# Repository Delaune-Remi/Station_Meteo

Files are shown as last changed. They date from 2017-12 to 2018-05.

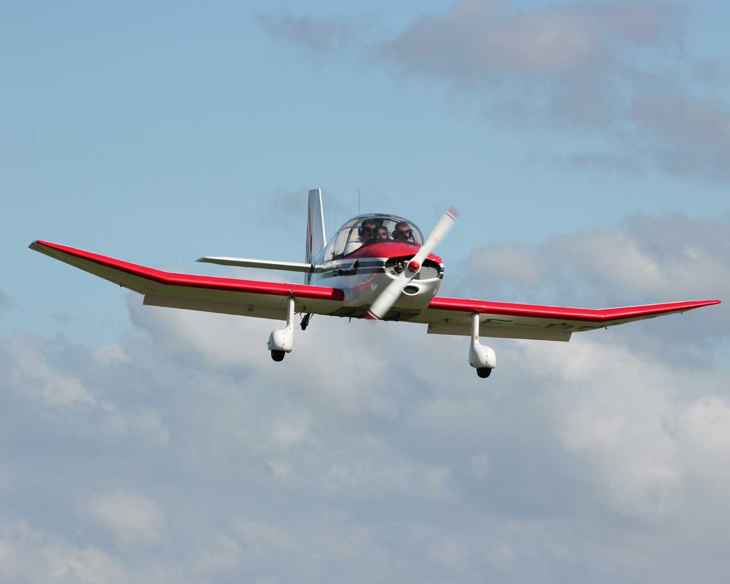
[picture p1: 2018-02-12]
Partie_Alexandre/Test_Unitaire/Prototype_HTML/images/fond.jpg

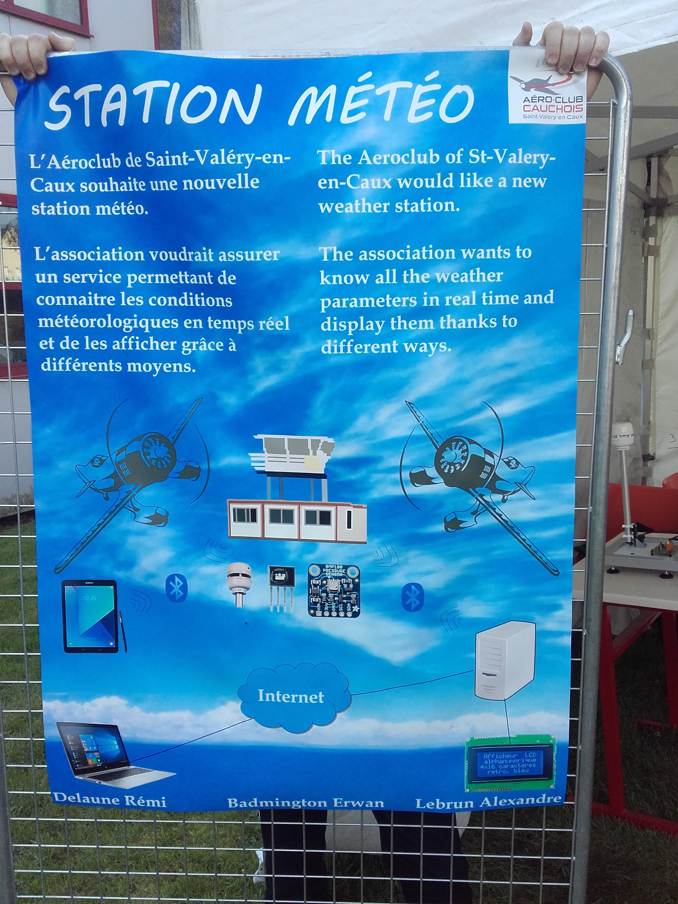
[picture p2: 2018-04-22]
Partie_Remi/Images/IMAGE PROJET/Poster.jpg

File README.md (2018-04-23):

<p  align="center">
  
  
</p>

---

<h1 align="center"> Station Meteo </h1>

---

<h2 align="center"> Presentation  </h2>

---

Station Meteo

<h4 align="center">Lien vers l'Aerodrome de Saint-Valery-En-Caux : http://aeroclub.cauchois.free.fr/</h4>

---

<h2 align="center"> Sommaire </h2>

---

* <a href="https://github.com/Delaune-Remi/Station_Meteo/tree/master/Analyse_Fonctionnelle" title="SysML">Analyse Fonctionnelle</a>
* <a href="https://github.com/Delaune-Remi/Station_Meteo/tree/master/Compte%20Rendu" title="Compte Rendu">Compte Rendu</a>
* <a href="https://github.com/Delaune-Remi/Station_Meteo/tree/master/Documentation" title="Documentation Technique">Documentation</a>
* <a href="https://github.com/Delaune-Remi/Station_Meteo/tree/master/Partie_Alexandre" title="Etudiant 2">Partie Alexandre</a>
* <a href="https://github.com/Delaune-Remi/Station_Meteo/tree/master/Partie_Erwan" title="Etudiant 3">Partie Erwan</a>
* <a href="https://github.com/Delaune-Remi/Station_Meteo/tree/master/Partie_Remi" title="Etudiant 1">Partie Remi</a>

---

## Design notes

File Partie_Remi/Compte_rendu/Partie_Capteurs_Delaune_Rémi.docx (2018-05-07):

Partie Capteurs

Projet Station Météo

Delaune Rémi

05/02/2018

Cette partie recense les différents capteurs et protocoles utilisé pour la station Météorologique

# Tables des Matières

# Introduction

Cette partie essentielle au bon fonctionnement de la station météorologique gère tous les capteurs qui seront placés en haut du mât de l’aéroclub cauchois représenté ci-dessous, les capteurs sont au nombre de 3, un capteur CV3F (girouette) utilisant le protocole NMEA, un capteur d’hygrométrie et un capteur de pression dont les fonctionnements seront expliqués.

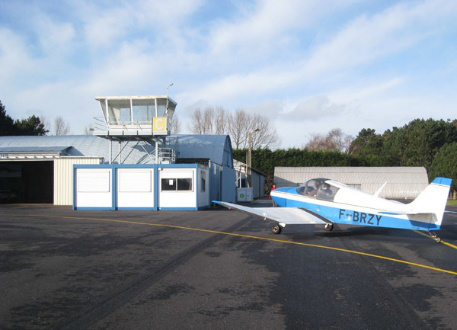
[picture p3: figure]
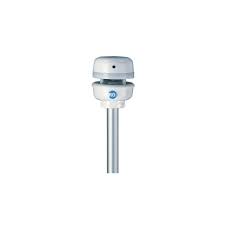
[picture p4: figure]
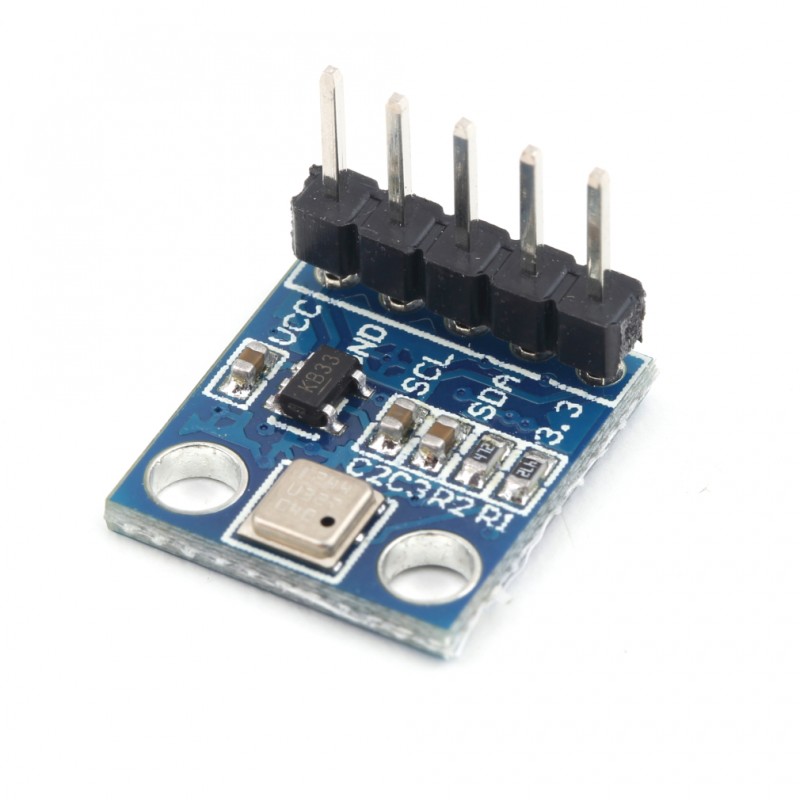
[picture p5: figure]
RÃ©sultat de recherche d'images pour "BMP180"
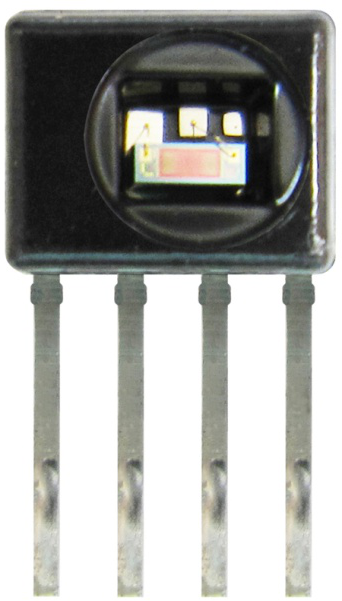
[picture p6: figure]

De plus, pour pouvoir communiquer entre les différentes parties du projet, j’ai proposé un protocole de transmission, le protocole INIMEAC.

Suite à de multiples tests avec l’application Android qui ont permis de déceler un problème de décodage de la trame par celle-ci, m’a amené à créer 2 protocoles INIMEAC en collaboration avec les autres parties dont le fonctionnement seront expliqués et détaillés.

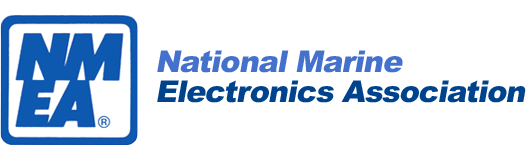
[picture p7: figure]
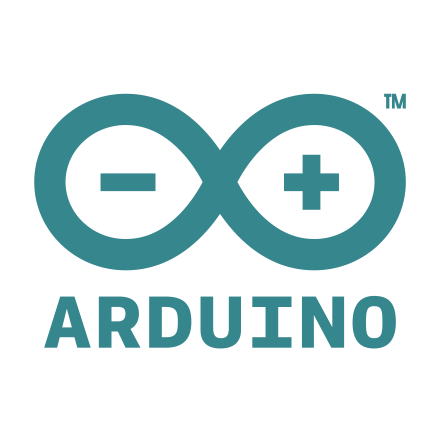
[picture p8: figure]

# Capteur CV3F

# Capteur CV3F

## Description:

Le capteur CV3F est une girouette ayant trois principales fonctions qui sont :

1. La mesure de la vitesse du vent
2. La direction du vent
3. La température de l'air

Afin de communiquer avec les différents systèmes, le capteur utilise les trames NMEA0183.

## Norme NMEA0183:

La norme NMEA0183 est spécialisé dans la communication entre équipements marins dont les équipements GPS (Global Positioning System). Celle-ci utilise une simple communication série pour transmettre une "phrase" à un ou plusieurs équipements, elle utilise le codage ASCII.

Exemple de trame NMEA0183:

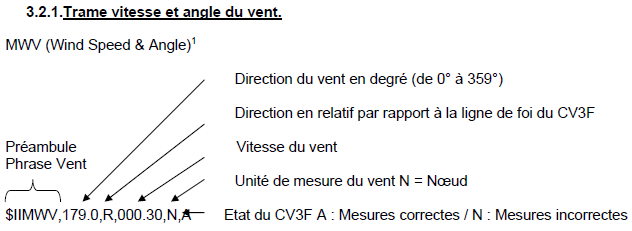
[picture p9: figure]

# Capteur CV3F

Afin d'établir une communication entre le capteur CV3F et la carte Arduino, il est nécessaire d'adapter les tensions car le capteur envoie une tension de sortie est du différentiel en 0-12V, tandis que la carte Arduino tolère une tension comprise entre 0 et 5V.

## Adaptation de tensions:

Pour faire cette adaptation de tensions, la méthode utilisé est le pont diviseur de tensions comme défini ci-dessous:

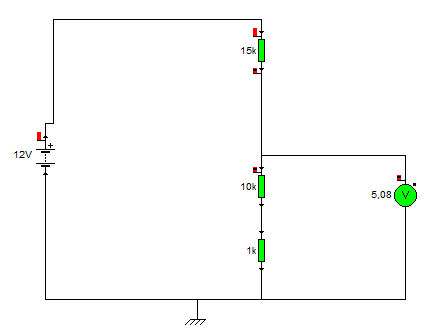
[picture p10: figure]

## Branchement du Capteur:

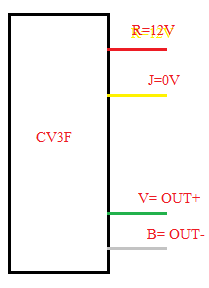
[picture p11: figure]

# Capteur CV3F

Le branchement du capteur CV3F est représenté ci-dessus, la sortie "OUT+" est relié au pont diviseur de tension pour sortir du 5V max en entrée de l'Arduino.

Les sorties "OUT+" et "OUT-" sont des sorties différentielles permettant la transmission des données du capteur (trame NMEA0183). La sortie "OUT-" n'est pas relié au système car elles sont en différentielle.

## Sécurité du Capteur:

Afin d'améliorer la sécurité du capteur et du système, j'ai ajouté une gaine thermique pour éviter tout risques d'arc-électrique.

## Programme pour récupérer les trames NMEA0183:

Pour récupérer les trames NMEA0183, j'ai réalisé le programme suivant:

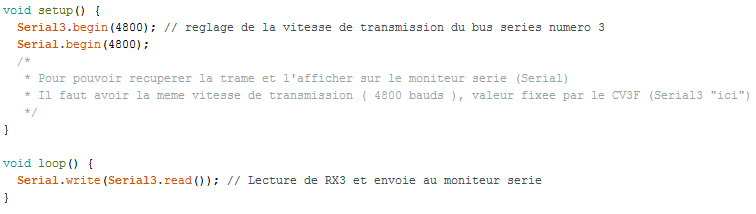
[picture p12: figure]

Lecture de la trame NMEA0183 reçue sur le moniteur Série:

# Capteur BMP180

# Capteur BMP180:

## Description:

Le capteur BMP180 est un capteur de pression ayant trois principales fonctions qui sont :

1. La pression
2. L'altitude
3. La température de l'air

Pour communiquer avec les différents systèmes, le capteur utilise le protocole I2C.

Afin de répondre au cahier des charges données, j'ai choisi de prendre le capteur de pression BMP180 pour acquérir la pression et la température de l'air, le capteur à une plage de pression allant de 950Hpa à 1050Hpa avec une précision de 0,12Hpa et une plage de température allant de -40°C à 85°C avec une résolution de 0,1°C.

De plus, il est indispensable de récupérer la température à l'aide du capteur BMP180 car la plage de température du capteur CV3F n'est pas suffisant et n'accepte pas les valeurs négatives.

Ce capteur correspond bien au cahier des charges qui a donné comme critères, une précision de pression de 1Hpa avec une précision de température de 0,5°C.

# Capteur BMP180

## Programme pour récupérer la température et la pression :

Le programme réalisé est le suivant:

La partie pour récupérer la température est ci-dessous:

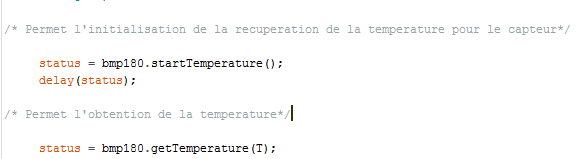
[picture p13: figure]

La partie permettant de récupérer la pression est ci-dessous:

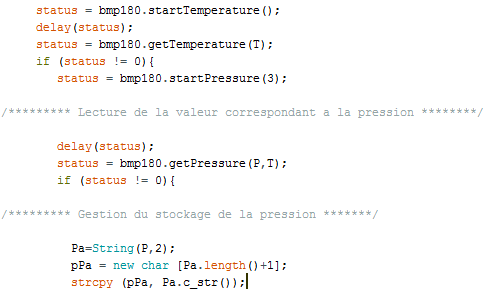
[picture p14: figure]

# Capteur BMP180

## Résultats des récupérations :

Récupération de la pression:

Récupération de la température

# Capteur HIH 8120

# Capteur HIH 8120 :

## Description :

Le capteur HIH 8120 est un capteur d'humidité permettant de mesurer 2 grandeurs physiques qui sont:

- La Température
- L'Hygrométrie

Afin de répondre au cahier des charges concernant la précision du capteur, j'ai opté pour le capteur HIH 8120 qui a une précision de 2 % pour l'hygrométrie et de 0,5 °C pour la température alors le cahier des charges nous oblige d'avoir une précision en température de 0,5°C ainsi qu'une précision de 2% pour l'humidité.

De plus le capteur HIH 6130 proposé au début du projet ne correspond pas à ces critères alors que le capteur choisi correspond parfaitement.

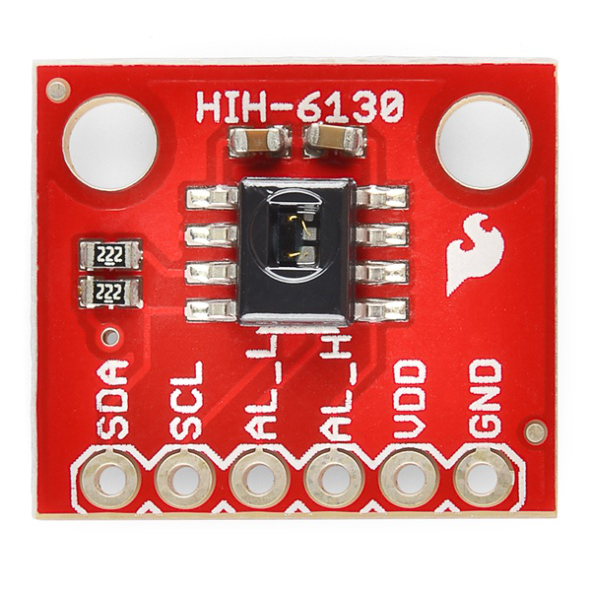
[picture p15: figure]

## Tests Unitaires pour récupération de l'hygrométrie :

# Capteur HIH 8120

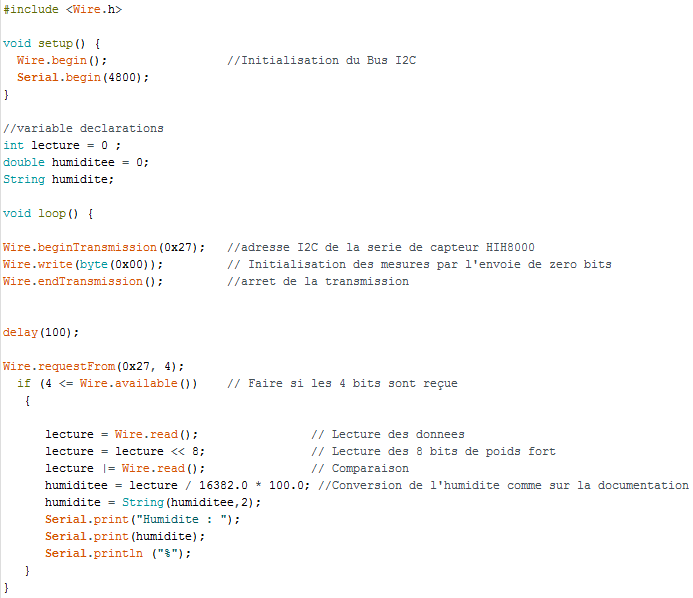
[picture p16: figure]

## Résultats des récupérations :

Le résultat est le suivant :

# Protocole INIMEAC

# Protocole INIMEAC :

Le protocole INIMEAC est un protocole qui permet de communiquer entre les différentes parties, entre autres il permet la transmission des données récupéré via les différents capteurs.

Suite à de multiples tests, ce protocole c’est scindé en 2 protocoles INIMEAC différents à cause des applications les utilisant, il y a le protocole initial pour communiquer entre les capteurs et la partie serveur web/afficheur, d’autres part un deuxième protocole qui est destiné à l’application Android, c’est 2 protocoles utilisent la norme Bluetooth v.2.0, de ce fait la distance maximale de transmission est limité à 20 mètres, la vitesse de transmission des données a été mis à 9600 Bauds.

## Protocole INIMEAC pour Serveur Web:

Ce protocole sert

© Projet Station Météo Page 12

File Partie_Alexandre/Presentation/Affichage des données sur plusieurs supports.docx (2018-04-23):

Affichage des données sur plusieurs supports

LEBRUN Alexandre

# Présentation

Cette partie du projet consiste à afficher les données reçu par la liaison série Bluetooth. Ces données seront afficher sur 2 afficheurs I2C puis sera visualisable sur un navigateur web. Suite au cahier des charges, nous avons eu besoin de deux afficheurs, de 2 lignes et de 16 caractères, au lieu d'un seul à cause du manque de place.

## Montage globale :

Voici le montage globale concernant ce projet ci-dessous :

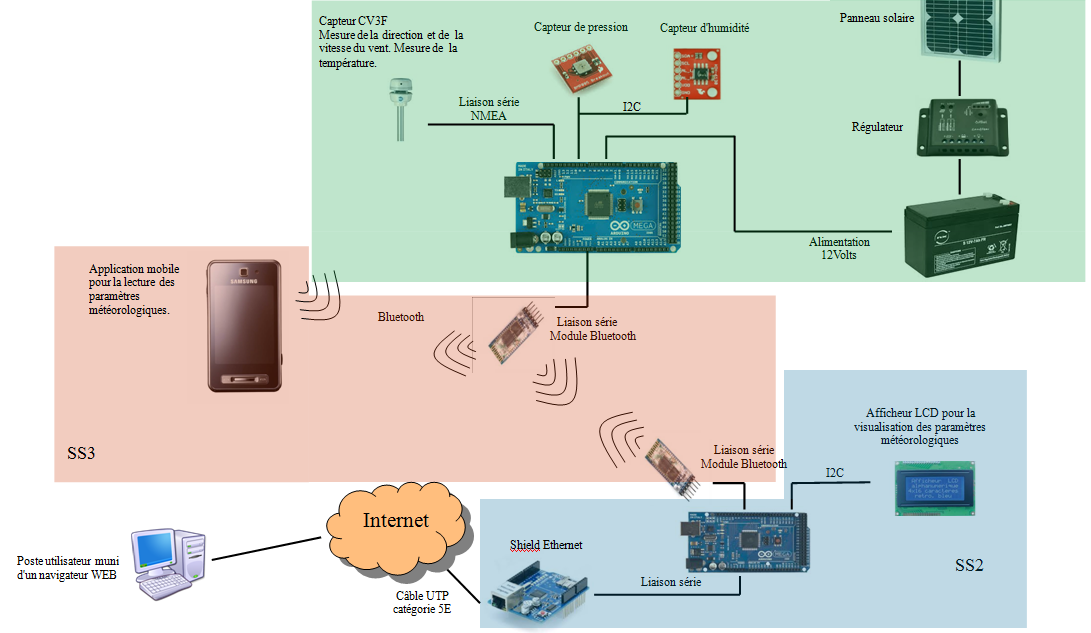
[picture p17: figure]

# Présentation du matériel

## Carte Arduino MEGA 2560 :

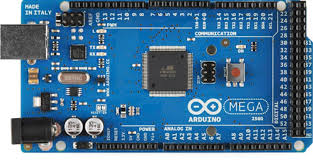
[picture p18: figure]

Cette carte permet de contrôler le flux Bluetooth la gestion des afficheurs, cette MEGA possède 256Ko d'espace mémoire.

## Shield Ethernet :

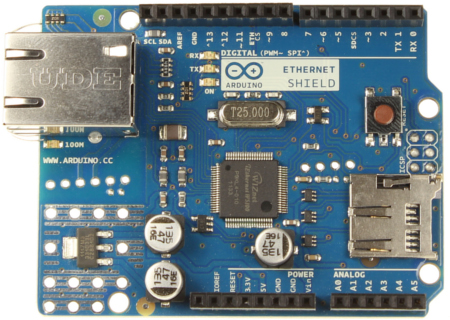
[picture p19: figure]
RÃ©sultat de recherche d'images pour "Shield ethernet"

Ce Shield permet de stocker un site web en mémoire grâce à une carte SD ou directement sur la mémoire de l'arduino, elle possède 16Ko d'espace mémoire et un emplacement SD ( Cette emplacement SD n'est pas utilisée ), Ce Shield Ethernet est relié avec la carte Arduino 4 broches SCLK MOSI MISO SS.

Le bus SPI : Ce bus est un protocole d'échanges de données qui travailles en full-duplex ( dans les deux sens ), ce bus permet la communication des données entre appareil par un protocole maître/esclave, le maître comme le nom l'indique gère tout. Ce bus envoie des informations sous forme binaire 0 ou 1 et utilise 4 signaux logiques :

- SCLK — Serial Clock, Horloge (généré par le maître)
- MOSI — Master Output, Slave Input (généré par le maître)
- MISO — Master Input, Slave Output (généré par l'esclave)
- SS — Slave Select, Actif à l'état bas (généré par le maître)

## Câble RJ45 :

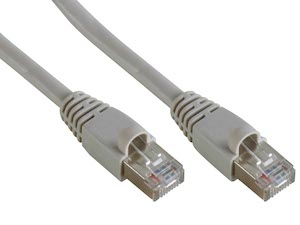
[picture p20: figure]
La prise RJ45 (http://www.lextronic.fr)

La prise RJ45 est une prise permettant d'interconnecter un appareil sur le réseau ici notre Shield Ethernet au réseau. Dans les spécifications le câble RJ45 doit être de pair torsadée non blindée ( UTP ) et de catégorie 5E.

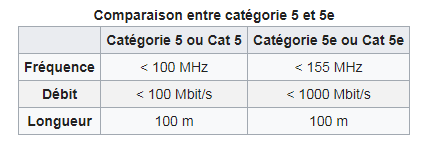
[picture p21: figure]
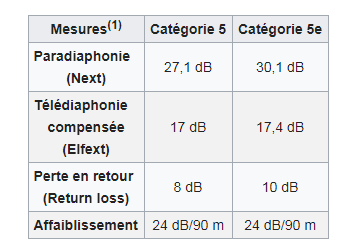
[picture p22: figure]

## Afficheur 2x16 I2C :

Cette afficheur fonctionne avec un module I2C CLCD420C, comme le nom l'indique l'afficheur fonctionne avec le bus I2C.

le bus I2C : Ce bus est un bus série asynchrone en half-duplex ( un sens à la fois ) il est multi-maître et multi-esclave, ce bus utilise deux signaux ( et une masse commune ) :

- SCL (Serial Clock) : l'horloge commune à tous les équipements,
- SDA (Serial Data) : la ligne portant les données.

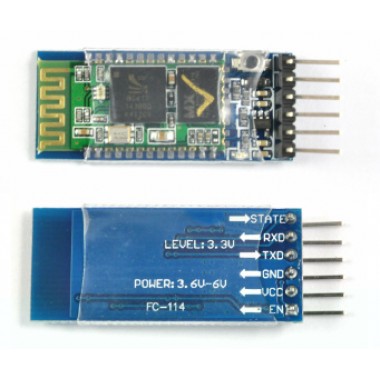
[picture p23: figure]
RÃ©sultat de recherche d'images pour "Module HC-05 bluetooth"

## Module HC-05 :

Ce module Bluetooth à été configuré par l'étudiant 3 Badmington Erwan, cet étudiant à configuré ce module en mode réception ce qui permet la réception du signal émit par les capteurs se trouvant sur la carte de l'étudiant 1 Delaune Rémi.

Nous avons décider de mettre les modules Bluetooth émission et réception sur les broches du port série 3 de la carte Arduino.

## Montage :

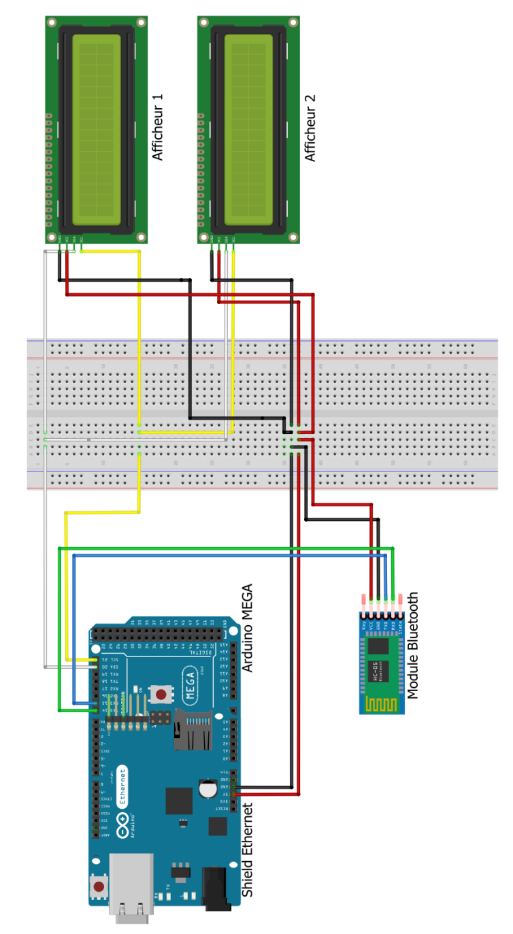
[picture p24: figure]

Explication du montage :

NOIR : On réalise une masse commune sur la platine

ROUGE : On réalise un 5V commun sur la platine

SCL : On réalise un SCL commun sur la platine

SDA : On réalise un SDA commun sur la platine

TX3 : Relié au RX du module Bluetooth

RX3 : Relié au TX du module Bluetooth

# Test Unitaire

Chaque test unitaire ont été réalisés sous l'environnement de travail ( IDE ) Arduino, Les ressources utilisées sont arduino.cc, openclassroom.com et github.com

## Test Reception Bluetooth :

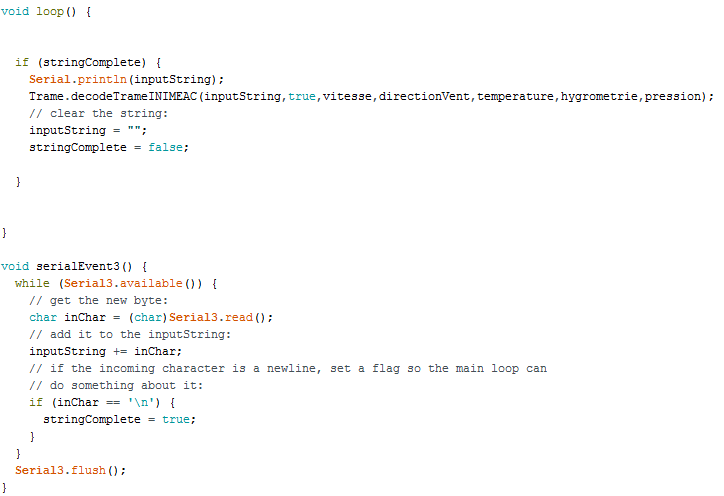
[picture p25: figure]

J'ai repris l'exemple du serialEvent se trouvant sur le site arduino.cc

On reçoit bien la trame que m'envoie Rémi

avec Ici : 0,1 kts en vitesse vent, 271° en direction vent, 22,55°C en temperature, 56,61% pour l'humidité et 1000,26 hPa en pression atmospherique.

## Test Afficheur :

Dans ce test unitaire j'ai testé l'affichage du mot bonjour sur l'afficheur lcd cette afficheur possède une bibliothèque CLCD.h trouvé sur internet.

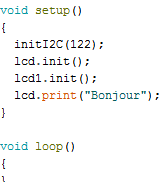
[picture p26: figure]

On affiche bien bonjour sur l'afficheur portant l'adresse 0x00 qui est réglable sur le module CLCD

## Test shield ethernet :

J'ai crée une adresse MAC pour le shield Ethernet qui est : 90-98-97-00-05-AB et j'ai fais une réservation sur le serveur DHCP du lycée pour mon adresse IP pour qu'il appartiennent sur le même réseau local j'ai décidé l'adresse suivante : 192.168.190.123.


## Dans ce test on affiche les informations côtés client : quel navigateur utilise t'il, quel paquet envoie t-il, à quel adresse il l'envoie, etc...

## Test page HTML :

Dans ce test unitaire je souhaite crée une page HTML qui serait capable de lire des broches de l'arduino je vous présente ce code ci-dessous :


Dans ce test on lit les valeurs lisibles sur les broches de A0 à A5 avec une petite interface sur le navigateur web le résultat est le suivant :


Avec ce test unitaire j'ai pu faire un prototype du site web final sous notepad++ :


J'ai pu réaliser par la suite un prototype d'interface pour l'afficheur I2C

Création d'une bibliothèque pour crée des caractères spéciaux pour afficheur I2C crée avec Arthur Langlois


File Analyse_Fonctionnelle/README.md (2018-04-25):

<h1 align="center"> Presentation </h1>

<table>
<tr align="center">
<td colspan="2">Vous trouverez dans le fichier Station_Meteo.eap les differents diagrammes presentes ci-dessous	 
ce fichier est ouvrable avec Entreprise Architect.
</td>
<tr align="center">
<td>Le fichier Scenario_Cas__Utilisation.odt contient les scenarios que la station meteo peut realiser. 
</td>
</tr>
</table>

---

#### _Exigence.png_
<p  align="center">
  
</p>

---

#### _UseCase.png_
<p  align="center">
  
</p>

---

#### _Sequence.png_ 
<p  align="center">
  
</p>

---

#### _DefinitionBlocs.png_
<p  align="center">
  
</p>

---

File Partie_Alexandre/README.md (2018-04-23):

---

<h1 align="center"> Sommaire </h1>
<p  align="center">
  
</p>

---

* <a href="https://github.com/Delaune-Remi/Station_Meteo/tree/master/Partie_Alexandre/Bibliotheque" title="Pour Arduino">Bibliotheque</a>
* <a href="https://github.com/Delaune-Remi/Station_Meteo/tree/master/Partie_Alexandre/Image" title="Image">Image</a>
* <a href="https://github.com/Delaune-Remi/Station_Meteo/tree/master/Partie_Alexandre/Presentation" title="Presentation">Presentation</a>
* <a href="https://github.com/Delaune-Remi/Station_Meteo/tree/master/Partie_Alexandre/Programme_Final" title="Programme Final">Programme Final</a>
* <a href="https://github.com/Delaune-Remi/Station_Meteo/tree/master/Partie_Alexandre/Test_Unitaire" title="Test Realiser">Test Unitaire</a>

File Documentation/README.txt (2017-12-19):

Cette partie servira a stocker les documentations utile pour le projet

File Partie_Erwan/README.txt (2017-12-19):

Cette partie permet a l'etudiant Erwan Badmington de gerer sa partie du Projet (Application Android)

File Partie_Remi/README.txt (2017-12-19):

Cette partie permet a l'etudiant Remi Delaune de gerer sa partie du Projet (Gestion des capteurs)

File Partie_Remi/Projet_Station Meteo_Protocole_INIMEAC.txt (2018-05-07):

Protocole INIMEAC :

&#!INIMEAC;!SWD::000.00::KTS;!DWD::000.00::D;!TMP::00.00::C;!RHY::000.00::%;!RPA::1013.25::hPa;!VAD::N:*

Légende:

-INIMEAC : Nom de la trame

-SWD: Speed Wind
	*VitesseVent : Valeur de la vitesse du vent
	*Unité : L'unité sera en Noeud (KTS) 

-DWD: Direction Wind
	*DirectionVent: Valeur de la direction du vent
	*Unité: L'unité sera en Degrés (D) 

-TMP: Température
	*TemperatureAir: Valeur de la température
	*Unité: L'unité sera en Degrés Celsius (C)

-RHY: Hygrométrie Relative
	*Hygrométrie: Valeur du taux d'humidité
	*Unité: L'unité sera en pourcentage (%)

-RPA: Pression Atmosphérique Relative
	*PressionAtmosphérique: Valeur de la pression Atmosphérique
	*Unité: L'unité sera en hPa (hPa)

-VAD: Validité des infos de la Trame
	*Validité: Renvoie l'état de validité de la trame (Y pour valide, N pour non valide)

Début de la trame: (&#!)

Séparateur d'informations: (;!)

Séparateur de données: (::)

Fin de la trame: (:*)

© DELAUNE Rémi

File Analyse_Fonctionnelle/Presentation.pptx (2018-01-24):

## Présentation Station météo

Lycée Raymond queneau 2017/2018


## Introduction

Une image contenant extérieur, route, ciel, herbe Description générée avec un niveau de confiance très élevé
Une image contenant ciel, extérieur, bâtiment Description générée avec un niveau de confiance très élevé

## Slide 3

Une image contenant capture d’écran Description générée avec un niveau de confiance très élevé

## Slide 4

Une image contenant texte, carte Description générée avec un niveau de confiance très élevé

## Différents scénarios

Une image contenant capture d’écran Description générée avec un niveau de confiance très élevé
Une image contenant capture d’écran Description générée avec un niveau de confiance très élevé

## Suite des Scenarios

Une image contenant capture d’écran Description générée avec un niveau de confiance très élevé
Une image contenant capture d’écran Description générée avec un niveau de confiance très élevé

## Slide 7


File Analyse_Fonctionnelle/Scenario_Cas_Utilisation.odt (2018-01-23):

| Étudiant 1 : Rémi Étudiant 2 : Alexandre Étudiant 3 : Erwan

Navigateur Web

Cas d'utilisation | Visualiser les informations par un navigateur web
Résumé | Permet à l'utilisateur d'accéder aux données grâce à un site Web
Acteurs | Utilisateur, Navigateur Web, Environnement
Date de création | 9 Janvier 2018
Date de dernière modification | 23 Janvier 2018
Version | 1.0
Auteur | Lebrun Alexandre , Delaune Rémi , Badmington Erwan

Scénario Principal

Utilisateur | Navigateur Web | Environnement
N1 : Connexion au site Web
| | N2 : Demande d'informations
| | N3 : Envoie des informations
| N4 : Affichage de la page Web

Application

Cas d'utilisation | Accéder à l'application
Résumé | Permet à l'utilisateur d'accéder aux données grâce à une application
Acteurs | Utilisateur, Application, Environnement
Date de création | 9 Janvier 2018
Date de dernière modification | 23 Janvier 2018
Version | 1.0
Auteur | Lebrun Alexandre , Delaune Rémi , Badmington Erwan

Scénario Principal

Utilisateur | Application | Environnement
N1 : Connexion à l'application
| N2 : Demande d'informations
| | N3 : Envoie des données
| N4 : Affichage des données
N5 : Changement d'unité
| N6 : Affichage des données

Afficheur LCD

Cas d'utilisation | Visualiser par un afficheur LCD
Résumé | Permet à l'utilisateur d'accéder aux données grâce à un afficheur LCD
Acteurs | Navigateur Web, Afficheur LCD
Date de création | 9 Janvier 2018
Date de dernière modification | 23 Janvier 2018
Version | 1.0
Auteur | Lebrun Alexandre , Delaune Rémi , Badmington Erwan

Scénario Principal

Navigateur Web | Afficheur LCD
N1 : Envoie des données
| N2 : Affichage des données

Environnement

Cas d'utilisation | Recevoir les données les données
Résumé | Permet d'actualiser les données météorologiques
Acteurs | Environnement, Navigateur Web, Application, Afficheur
Date de création | 9 Janvier 2018
Date de dernière modification | 23 Janvier 2018
Version | 1.0
Auteur | Lebrun Alexandre , Delaune Rémi , Badmington Erwan

Scénario Principal

Navigateur Web | Application | Afficheur LCD | Environnement
| | | N1 : Envoie des données
N2 : Envoie des données
| | | N3 : Envoie des données

Scénario Diagramme de cas d'utilisation

https://github.com/Delaune-Remi/Station_Meteo/tree/master/Analyse_Fonctionnelle/Scenario_Cas_Utilisation.odt (https://github.com/Delaune-Remi/Station_Meteo/blob/master/Analyse_Fonctionnelle/Scenario_Cas_Utilisation.odt) 4/4

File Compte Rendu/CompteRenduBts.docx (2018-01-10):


La station météo

Projet de fin d'études

DELAUNE Rémi LEBRUN Alexandre BADMINGTON Erwan

2017/2018


# Table des Matières

# Introduction

Ce compte rendu présente l'utilisation d'une station météo, via le biais de différents capteurs, et d'une application Android pour la lecture des paramètres météorologiques par Bluetooth. Un site Web sera aussi créé pour la visualisation des paramètres météorologiques si l'on ne se trouve pas sur le site de l'aérodrome. Ce projet est réalisé par 3 élèves durant 5 mois. Cet aéroclub se trouve à Saint Valéry en Caux, en Haute Normandie.

St_Valery_en_Caux_aerodrome_070902_TWR
St_Valery_Vittefleur_050501_01

Ce projet regroupe plusieurs domaines d'activités comme par exemple le domaine de la télécommunication. On peut aussi citer le domaine de l'informatique, celui des systèmes embarqués et celui des mesures et de l'instrumentation.

# Dossier de spécifications

Trois parties d'études sont remarquables. Une partie concernant l'acquisition des paramètres météorologiques pour le premier étudiant. Pour le second étudiant, sa partie concernera le système numérique présent dans le local de préparation des vols. Finalement, le dernier étudiant s'occupera de la consultation des paramètres météorologiques pour les utilisateurs une fois arriver sur le terrain.

## Premier étudiant:

Le premier étudiant s'occupera de l'acquisition des paramètres météorologiques qui se situeront au haut d'un mât de 6 mètres de hauteur.


Pour assurer le bon fonctionnement du système même en cas de faible luminosité, il sera alimenté d'un panneau solaire équipé d'un régulateur et d'une batterie de 12V.


Ce système sera équipé de différents capteurs afin de pouvoir mesurer la pression atmosphérique avec une précision de ±1 Hpa (Unité: Hectopascal), la température à ±0,5 degrés près. Il pourra ensuite mesurer le taux d'hygrométrie (c'est à dire la quantité d'eau sous forme gazeuse dans l'air) à ±2% d'écart. Finalement, la vitesse et la direction du vent sans pièces mouvantes sera mesurée avec une technologie par ultrasons grâce à une girouette. L'ensemble des données seront transmises par Bluetooth au troisième étudiant toutes les 5 secondes.

Girouette

Régulateur

Panneau solaire

Batterie 12V

## Second étudiant:


Pour sa part, il devra récupérer les informations envoyées par le premier étudiant via Bluetooth toutes les 5 secondes. Il créera donc un site Web qui permettrons aux membres du club de consulter les paramètres météorologiques à distance depuis un accès à Internet sur le site de l'aérodrome. Ce site Web sera hébergé sur un serveur Web se trouvant sur une carte Arduino. On pourra trouver aussi un afficheur LCD pour voir en direct les paramètres météorologiques.

Serveur hébergé dans la carte Arduino


Shield Ethernet Arduino

## Troisième étudiant:


Quand à lui, il sera en charge de créer une application sous Android pour que les usagers aient accès aux informations météorologiques quand ils sont sur le site. Il récupèrera lui aussi les informations du premier étudiant toutes les 5 secondes. Il se chargera de mettre en œuvre la communication Bluetooth. Sur l'application, l'utilisateur pourra choisir les différentes unités d'affichage, c'est à dire la vitesse du vent en m/s, km/h ou en kts (nœuds), ainsi que la température en degré Celsius ou en Fahrenheit.

Module Bluetooth HC-05

Périphérique servant d'application Android

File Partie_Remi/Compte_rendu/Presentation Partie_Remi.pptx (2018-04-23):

## Présentation Station météo

Lycée Raymond queneau 2017/2018


## Introduction

Une image contenant extérieur, route, ciel, herbe Description générée avec un niveau de confiance très élevé
Une image contenant ciel, extérieur, bâtiment Description générée avec un niveau de confiance très élevé

## Partie Capteur Descriptif de la partie

Résultat de recherche d'images pour "anémomètre avion"
Résultat de recherche d'images pour "rose des vents"
Résultat de recherche d'images pour "baromètre$"
Résultat de recherche d'images pour "hygrometre"

## Schéma partie capteur


## Image du Montage de la partie Capteur


## Capteur CV3F Trame Attendue et Adaptation de tension


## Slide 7

## Capteur CV3F Tests Unitaires (Trame MWV et XDR)


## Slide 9

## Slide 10


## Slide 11


## Ce qui me reste à faire !


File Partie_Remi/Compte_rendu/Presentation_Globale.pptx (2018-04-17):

## Présentation Station météo

Lycée Raymond queneau 2017/2018


## Introduction

Une image contenant extérieur, route, ciel, herbe Description générée avec un niveau de confiance très élevé
Une image contenant ciel, extérieur, bâtiment Description générée avec un niveau de confiance très élevé

## Présentation du projet


Internet


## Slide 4

Une image contenant capture d’écran Description générée avec un niveau de confiance très élevé

## Partie étudiant 1

## Partie étudiant 2

## Partie étudiant 3

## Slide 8

Une image contenant texte, carte Description générée avec un niveau de confiance très élevé

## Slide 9


## étudiant 1: Partie Capteur Descriptif

Résultat de recherche d'images pour "anémomètre avion"
Résultat de recherche d'images pour "rose des vents"
Résultat de recherche d'images pour "baromètre$"
Résultat de recherche d'images pour "hygrometre"

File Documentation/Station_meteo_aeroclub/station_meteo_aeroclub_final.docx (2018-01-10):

BTS Systèmes Numériques

Option : EC

E 6-2 – PROJET TECHNIQUE

Dossier de présentation et de validation du projet (consignes et contenus)

SESSION : 2018

Etablissement de Formation (Ville) : Lycée Raymond Queneau 76190 Yvetot
N° du projet : 2018-01 | Nom du projet : Station météo pour l'aéroclub

Projet nouveau | Oui [x] Non [ ] | | Projet interne: | Oui [ ] Non [x]
Délai de réalisation | 17 semaines (180 heures) | | Statut des étudiants: | Formation initiale [x] Apprentissage [ ]
Spécialité des étudiants | EC [x] IR [ ] Mixte [ ] | | Nombre d’étudiants: | 3
Professeurs responsables | Pisak Sébastien

Sommaire

# 1 – Présentation et situation du projet dans son environnement

## 1.1 – Contexte de réalisation

Constitution de l’équipe de projet : | Étudiant 1 EC [x] IR [ ] | Étudiant 2 EC [x] IR [ ] | Étudiant 3 EC [x] IR [ ] | Étudiant 4 EC [ ] IR [ ]
Projet développé : | Au lycée ou en centre de formation [x] En entreprise [ ] Mixte [ ]
Type de client ou donneur d’ordre (commanditaire) : | Entreprise ou organisme commanditaire : Oui [x] Non [ ] Nom : Aéroclub Cauchois Adresse : Bourg 76490 Saint-Sylvain Contact : M Delaître Daniel Origine du projet : - Idée : Lycée [ ] Entreprise [x] - Cahier des charges : Lycée [ ] Entreprise [x] - Suivi du projet : Lycée [x] Entreprise [ ]
Si le projet est développé en partenariat avec une entreprise : | Nom de l’entreprise : Aéroclub Cauchois Adresse de l’entreprise : Bourg 76490 Saint-Sylvain Adresse site : Aeroclub.cauchois.free.fr Tél. : 06.13.42.12.37 Courriel : aeroclubcauchois@gmail.com

## 1.2 – Présentation du projet

L'aéroclub Cauchois existe depuis la fin de la deuxième guerre mondiale. C'est un aéroclub qui se trouve sur l'ancienne base militaire américaine Lucky Strike. Il dispose d'une flotte de quatre avions, et regroupe une centaine d'adhérents. Chaque membre du club peut, via une application Internet réserver un avion de chez lui. Il se présente ensuite à l'aéroclub, prend la clef des hangars dans un boite à clefs, puis dispose de l'avion pour son vol.

Cet aérodrome ne dispose pas de contrôleur aérien. A ce titre, il n'y a donc pas de station météo officielle, et personne pour donner les informations concernant la direction et la vitesse du vent aux usagers du terrain. Le club s'est donc plusieurs fois équipé de stations météos "grand public", mais celles-ci, de part leurs pièces mobiles, ne durent guère longtemps, et laisse à désirer en terme de précision au fil du temps (surtout pour les pièces mobiles de l'anémomètre et de la girouette). Il est, de plus, souvent difficile de garantir la maintenance des parties se trouvant sur le mat (remplacement des piles pour la transmission sans fils notamment).

Le club souhaiterait donc disposer d'une station météo fiable, robuste et bon marché, qui permettrait de donner les informations essentielles à ses membres pour préparer un vol. Chacun pourrait consulter de chez lui les paramètres météorologiques sur le site de l'aérodrome via un ordinateur relié à Internet, ou grâce à un terminal Android (Smartphone ou tablette équipés du Bluetooth®) une fois arrivé à l'aéroclub.

St_Valery_Vittefleur_050501_01
St_Valery_en_Caux_aerodrome_070902_TWR

## 1.3 – Situation du projet dans son contexte

Domaine d’activité du système support d’étude : | [x] télécommunications, téléphonie et réseaux téléphoniques ; [x] informatique, réseaux et infrastructures ; [ ] multimédia, son et image, radio et télédiffusion ; [x] mobilité et systèmes embarqués ; [ ] électronique et informatique médicale ; [x] mesure, instrumentation et micro-systèmes ; [ ] automatique et robotique.

## 1.4 – Cahier des charges – Expression du besoin

L'équipe d'étudiants se propose donc de réaliser un système d'acquisition des paramètres météorologiques, ainsi qu'un système de mise à disposition pour les membres du club. On peut donc déjà dégager trois grandes parties.

- Pour ce qui concerne la partie acquisition des paramètres météorologiques :
  - Comme l'acquisition est réalisée en haut d'un mat de 6 mètres, le système devra être alimenté à partir d'un panneau solaire (afin de garantir son autonomie énergétique et limiter les connectiques en cuivre). Ce panneau sera équipé d'un régulateur et d'une batterie 12V afin de garantir l'acquisition des mesures, même en l'absence de soleil (au crépuscule par exemple, un avion pouvant voler 30 minutes avant le lever du soleil jusqu'à 30 minutes après le coucher).
  - Le système devra pouvoir mesurer la pression atmosphérique avec une précision de ±1 Hpa.
  - Le système devra pouvoir mesurer la température avec une précision de ±0,5 degrés.
  - Le système devra pouvoir mesurer le taux d'hygrométrie (qui permet de calculer le point de rosé et donc la base des nuages et le taux d'humidité) avec une précision de ±2%.
  - Le système devra donc pouvoir mesurer la vitesse et la direction du vent sans pièces mobiles. La technologie employée sera celle que l'on retrouve souvent sur les bateaux, à savoir une mesure par ultrasons.
  - Le système complet se trouvant sur le mat communiquera, toutes les 5 secondes, l'ensemble des données en Bluetooth à un autre système numérique se trouvant dans le local de préparation des vols.
- Pour ce qui concerne le système numérique présent dans le local de préparation des vols :
  - Celui-ci devra récupérer via une liaison Bluetooth, toutes les informations issues du mat de façon cyclique toutes les 5 secondes.
  - N'ayant pas de contrainte filaire, ce système sera alimenté via une prise secteur (le local dispose de l'électricité et d'une arrivée Internet ADSL).
  - Ce système hébergera un site web qui permettra à l'ensemble des membres du club de voir les paramètres météorologiques sur le site de l'aérodrome.
  - Afin de vérifier le bon fonctionnement et l'acquisition des paramètres météorologiques, le système numérique présent dans le local disposera d'un petit afficheur LCD qui permettra de visualiser les données météo directement.
- Enfin il sera nécessaire de créer une application pour Smartphone et tablette (équipées d'Android) afin que les usagers puissent consulter les paramètres météorologiques une fois arrivé sur le terrain. Les données seront donc transmisses du mat en Bluetooth toutes les 5 secondes et récupérées par le Smartphone ou la tablette via l'application développée pour être affichées à l'écran. L'utilisateur pourra choisir différentes unités d'affichage :
  - vitesse du vent en m/s, en km/h ou en kts (nœuds).
  - température en degrés Celsius ou Fahrenheit.

# 2 – Spécifications

Mat contenant le système embarqué pour la mesure des paramètres météorologiques:

-vitesse et direction du vent

-température

-humidité

-pression

## 2.1 – Synoptique de l'architecture matérielle


Bluetooth

Bluetooth


Affichage des données météorologiques

Appareil mobile de type Smartphone ou tablette sous Android équipé d'une liaison sans fil Bluetooth, permettant la visualisation des paramètres météorologiques. Actualisé toutes les 5 secondes.

Internet


Serveur Web.

Local de préparation des vols (équipé d'un modem ADSL)

PC utilisateur équipé d'un navigateur Web

## 2.2 – Contraintes de réalisation

Contraintes financières (budget alloué) :

L'aéroclub étant sous le régime associatif (et régi par la loi de 1901), il dispose d'un budget très "serré". C'est pourquoi, le lycée se propose de réaliser un prototype avec le matériel présent au sein de la section. Une fois la maquette validée à la fin du projet, l'aéroclub disposera d'un budget de 1000 euros pour une réalisation sur site (qui ne sera pas assurée par les étudiants).

Contraintes de développement (matériel et/ou logiciel imposé / technologies utilisées) :

Le matériel et les technologies utilisées seront celles pratiquées par les étudiants au cours de leurs deux années de formations. A savoir le langage C++ avec l'IDE d'Arduino. Les systèmes embarqués seront à base de cartes Arduino Mega. Le site web utilisera les langages HTML5 et CSS2, avec possibilité d'utiliser du Javascript. Pour le matériel, les étudiants devront choisir, parmi les capteurs présents au sein de la section, ceux qui permettront de remplir les exigences du cahier des charges.

Contraintes qualité (conformité, délais, …) :

Les contraintes de fabrication et de qualités sont dictées par l'environnement physique dans lequel se trouvera le système final.

La documentation technique du système final devra également permettre à un non initié en électronique et informatique, d'installer et de mettre en œuvre le système à l'aéroclub. La procédure devra donc être des plus simples avec un maximum d'automatisation de l'ensemble (connexion Bluetooth, adressage IP, etc.)

La partie installée sur le mat (instruments de mesure, batterie et panneau solaire) devront résister aux intempéries. A ce titre, l'ensemble devra être IP54. A noter, que lors de la présentation du prototype pour la soutenance de projet, cette contrainte ne sera pas évaluée.

Contraintes de fiabilité, sécurité :

Les contraintes liées à l'environnement sont fortes et vont directement impacter les choix que devront réaliser les étudiants sur les composants et sur les technologies employées (système exposé aux intempéries, présence de hangars métalliques, etc..).

  - contrainte climatique (précipitation, froid, vent, etc..).
  - contrainte d'usure. Ce qui conditionne le choix des capteurs anémométriques.
  - contrainte de précision. Des mesures erronées pouvant directement mettre en danger la vie des pilotes, un soin tout particulier sera apporté au choix des capteurs et à leur fiabilité.

## 2.3 – Ressources mises à disposition des étudiants (logiciels / matériels / documents)

Seront mis à disposition des étudiants :

- l'ensemble des logiciels de développements (tel que l'IDE Arduino), et Enterprise Architect pour la modélisation SYSML.
- les bibliothèques pour l'utilisation des différents capteurs (I2C, série, etc..). Ces bibliothèques seront présentes sur Github et pourront, soit être utilisées telles quelles par les étudiants, soit être remaniées pour optimiser le fonctionnement du système à réaliser.
- la norme NMEA pour l'acquisition des trames issues de l'anémomètre et de la girouette
- la norme Bluetooth pour les modules de communication entre les deux cartes Arduino Méga et le système mobile (Smartphone ou tablette).
- une connexion Internet afin de pouvoir utiliser le logiciel en ligne AppInventor (pour la programmation de l'application mobile).
- une connexion Internet pour la recherche documentaire et l'utilisation du service web d'hébergement et de gestion de développement de logiciels Github.

L'ensemble des composants matériels :

- deux cartes Arduino Mega. L'une pour le système embarqué sur le mat, l'autre comme serveur web.
- une tablette pour la réalisation de l'application mobile (sous Android).
- trois ordinateurs pour la réalisation des applications embarquées dans les modules Arduino (sous Windows Seven) et pour l'application mobile (appareil sous Android)
- deux modules Bluetooth (de type HC-05) pour permettre la communication entre les deux cartes Arduino d'une part, et entre la carte Arduino présente sur le mat et le Smartphone d'autre part.
- un module Ethernet pour la réalisation du serveur Web.
- un afficheur led (4 lignes x 16 caractères) permettant un affichage en local des mesures sur la carte Arduino présente dans le local de préparation des vols (serveur Web).
- un panneau solaire 12V 10 Watts, avec une batterie 12V et un régulateur.
- un capteur de pression de type BMP180 (à déterminer par les étudiants en fonction du cahier des charges).
- un capteur d'humidité de type HIH6130 (à déterminer par les étudiants en fonction du cahier des charges).
- un capteur ultrason pour la mesure de la vitesse et de la direction du vent de type CV-3F du fabricant LCJ Capteurs (il dispose également d'une mesure de la température extérieure). Pour le prototype, les étudiants utiliseront le module fourni par Exxotest DEI-2112 et devront adapter les niveaux de tensions pour rendre le système compatible avec la carte Arduino.


# 3 – Répartition des tâches par étudiants

SS1

Il est possible de scinder l'ensemble en trois sous-systèmes

Capteur CV3F

Mesure de la direction et de la vitesse du vent. Mesure de la température.

Panneau solaire

Capteur de pression


Capteur d'humidité


Liaison série

NMEA

I2C

I2C

Régulateur


Alimentation 12Volts


Application mobile pour la lecture des paramètres météorologiques.


Liaison série

Module Bluetooth

Bluetooth

Afficheur LCD pour la visualisation des paramètres météorologiques


SS3

Liaison série

Module Bluetooth


Internet

connaitre-composants-ordinateur-configuration-pc-dcf0bb

Shield Ethernet

ethernet

SS2

Poste utilisateur muni d'un navigateur WEB

Liaison série

Câble UTP catégorie 5E

Répartition des fonctions ou cas d’utilisation par étudiant

| Travail à réaliser

Étudiant 1

EC [x] IR [ ]

SS1 : Réalisation du système numérique placé sur le mat.

L'étudiant devra dans un premier temps formaliser le cahier des charges avec les membres de son équipe en utilisant SYSML.

Il devra également définir avec ses collègues un protocole de communication pour l'échange des données entre son système, SS2 et SS3

Le système SS1 permettra l'acquisition de la pression, du taux d'hygrométrie, de la température ainsi que de la vitesse et de la direction du vent.

L'étudiant 1 devra choisir ses capteurs afin de respecter le cahier des charges et les mettre ensuite en œuvre.

Il sera nécessaire d'adapter la maquette Exxotest afin que les niveaux de tensions soient compatibles avec les entrées de la carte Arduino.

L'étudiant 1 réalisera également la mise en œuvre du système d'alimentation solaire et vérifiera que le kit fourni répond aux attentes du système en terme de puissance nécessaire (calcul de la consommation du système placé sur le mat avec l'ensemble de ses capteurs).

L'étudiant 1 n'aura pas à gérer la configuration du module Bluetooth (dédiée à l'étudiant 3). Il se "contentera" d'envoyer l'ensemble des données recueillies toutes les 5 secondes sur une liaison série.

Étudiant 2

EC [x] IR [ ]

SS2 : Réalisation du système numérique placé dans le local de préparation des vols.

L'étudiant devra dans un premier temps formaliser le cahier des charges avec les membres de son équipe en utilisant SYSML.

Il devra également définir avec ses collègues un protocole de communication pour l'échange des données entre son système, SS1 et SS3.

L'étudiant 2 devra réaliser un serveur web en associant une carte Arduino avec une carte Ethernet. Il présentera sous forme d'une page web les données météorologiques fournies par SS1.

Le site Web permettra à l'internaute de choisir les unités pour les différentes valeurs mesurées.

L'étudiant 2 réalisera également un système d'affichage en local, grâce à un afficheur LCD (4 lignes de 16 caractères) qui permettra de valider la bonne réception des données.

L'étudiant 2 n'aura pas à gérer la configuration du module Bluetooth (dédiée à l'étudiant 3).Il se "contentera" de récupérer les données envoyées par SS1 toutes les 5 secondes sur une liaison série.

Étudiant 3

EC [x] IR [ ]

SS3 : Réalisation de l'application mobile et mise en œuvre de la communication Bluetooth.

L'étudiant devra dans un premier temps formaliser le cahier des charges avec les membres de son équipe en utilisant SYSML.

Il devra également définir avec ses collègues un protocole de communication pour l'échange des données entre son système, SS1 et SS2.

L'étudiant 3 devra mettre en œuvre la communication Bluetooth (paramétrage des modules, choix du mode de transmission). Il fournira une solution "clef en main" à ses deux collègues qui utilisent ces modules.

L'étudiant 3 réalisera l'application mobile (en utilisant AppInventor) pour visualiser les paramètres météorologiques. Cette application se connectera en Bluetooth à l'émetteur se trouvant sur le mat de l'aérodrome (module SS1).

L'application devra permettre à l'utilisateur de choisir les unités pour les différentes grandeurs affichées.

## 3.1 – Visa du Chef d'établissement ou de son représentant

Monsieur le Proviseur : Aucomte Francis

# 4 – Exploitation Pédagogique – Compétences terminales évaluées :

| Électronique et Communications | Informatique et Réseaux | Étudiant 1 EC [x] | Étudiant 2 EC [x] | Étudiant 3 EC [x]
C2.1 | Maintenir les informations | | [x] | [x] | [x]
C2.2 | Formaliser l’expression du besoin | | [x] | [x] | [x]
C2.3 | Organiser et/ou respecter la planification d’un projet | | [x] | [x] | [x]
C2.4 | Assumer le rôle total ou partiel de chef | | [x] | [x] | [x]
C2.5 | Travailler en équipes | | [x] | [x] | [x]
C3.1 | Analyser un cahier des charges | | [x] | [x] | [x]
C3.3 | Définir l’architecture globale d’un prototype ou d’un système | | [x] | [x] | [x]
C3.5 | Contribuer à la définition des éléments de recette au regard des contraintes du cahier des charges | | [x] | [x] | [x]
C3.6 | Recenser les solutions existantes répondant au cahier des charges | | [x] | [x] | [x]
C3.8 | Élaborer le dossier de définition de la solution techniquement | | [x] | [x] | [x]
C3.9 | Valider une fonction du système à partir d’une maquette réelle | | [ ] | [ ] | [ ]
C3.10 | Réaliser la conception détaillée d’un module matériel et/ou logicielle | | [x] | [x] | [x]
C4.1 | Câbler et/ou intégrer un matériel | | [x] | [x] | [x]
C4.2 | Adapter et/ou configurer un matériel | | [x] | [x] | [x]
C4.3 | Adapter et/ou configurer une structure logicielle | Installer et configurer une chaîne de développement | [x] | [x] | [x]
C4.4 | Fabriquer un sous ensemble | Développer un module logiciel | [x] | [x] | [x]
C4.5 | Tester et valider un module logiciel et matériel | Tester et valider un module logiciel | [x] | [x] | [x]
C4.6 | Produire les documents de fabrication d’un sous ensemble | Intégrer un module logiciel | [x] | [x] | [x]
C4.7 | Documenter une réalisation matérielle / logicielle | | [x] | [x] | [x]

# 5 – Planification

Début du projet semaine 1 (lundi 8 janvier).

Revue 1 (R1) semaine 3 (jeudi 25 janvier).

Revue 2 (R2) semaine 7 (jeudi 22 janvier).

Revue 3 (R3) semaine 13 (jeudi 19 avril).

Remise du projet (Re) semaine 17 (vendredi 25 mai).

Soutenance finale (Sf) semaine ?

Livraison (Li) semaines 17(vendredi 27 mai).

# 6 – Condition d’évaluation pour l’épreuve E6-2

## 6.1 – Disponibilité des équipements

L’équipement sera-t-il disponible ? | Oui [x] | Non [ ]

## 6.2 – Atteintes des objectifs du point de vue client

Que devra-t-on observer à la fin du projet qui témoignera de l’atteinte des objectifs fixés, du point de vue du client :

- Le système numérique placé sur le mat, devra fournir l'ensemble des paramètres météorologiques demandé (pression, température, hygrométrie, vitesse et direction du vent).
- Le système numérique placé dans le local de préparation des vols, devra récupérer l'ensemble des paramètres météorologiques afin de les afficher sur l'écran LCD 4x16. Il devra fournir une IHM Web simple et conviviale permettant de visualiser et de choisir les unités pour les différentes valeurs.
- L'ensemble de la communication Bluetooth devra être fonctionnelle.
- L'application Android devra être opérationnelle et permettre de visualiser de façon simple et conviviale l'ensemble des paramètres météorologiques avec la possibilité de choisir les unités désirées.

## 6.3 – Avenants :

Date des avenants : Nombre de pages :

PLANNING PRÉVISIONNEL

| | | | | | | | | | | R | V | V | | | | | | R | V | V | | | | | D
Étudiant | | | | Repère | 7 – Description de la tâche | 0 | 0 | 0 | 0 | 0 | 0 | 0 | 0 | 0 | 1 | 1 | 1 | 1 | 1 | 1 | 1 | 1 | 1 | 1 | 2 | 2 | 2
A | B | C | D | tâche | | 1 | 2 | 3 | 4 | 5 | 6 | 7 | 8 | 9 | 0 | 1 | 2 | 3 | 4 | 5 | 6 | 7 | 8 | 9 | 0 | 1 | 2
X | X | X | | T1 | Présentation du projet | X
X | X | X | | T2 | Analyse et spécification du système | | X | X | X
X | X | X | | T3 | Elaboration du protocole de communication | | | | X | X | X
X | | | | T4 | Mise en œuvre des différents capteurs | | | | X | X | X
| X | | | T5 | Mise en œuvre le l'afficheur | | | | X | X | X
| | X | | T6 | Mise en œuvre des modules Bluetooth | | | | X | X | X
| | X | | T9 | Réalisation du prototype de l'IHM Android | | | | | | X | | | X
| X | | | T10 | Réalisation du prototype de l'IHM Web | | | | | | | | | X | X
X | | | | T11 | Codage de la sous fonction SS1 | | | | | | | | | | X | X | X | X | X | | | X | X | X | X
| X | | | T12 | Codage de la sous fonction SS2 | | | | | | | | | | X | X | X | X | X | | | X | X | X | X
| | X | | T13 | Codage de la sous fonction SS3 | | | | | | | | | | X | X | X | X | X | | | X | X | X | X
X | X | X | | T15 | Tests unitaires individuels de chaque classe | | | | | | | | | | | | X | X | X | | | X | X | X | X
X | X | X | | T16 | Intégration | | | | | | | | | | | | | | X | | | X | X | X | X | X
X | X | X | | T17 | Tests de validation | | | | | | | | | | | | | | | | | X | X | X | X | X | X
X | X | X | | T18 | Réalisation du dossier | | X | X | X | X | X | X | X | X | X | X | X | X | X | X | X | X | X | X | X | X | X

# 8 – Observation de la commission de Validation

Ce document initial : | [x] comprend 11 pages.
(À remplir par la commission de validation qui valide le sujet de projet) | [ ] a été validé par la Commission Académique de validation qui s’est réunie à , le / / 20

Contenu du projet : | Défini [ ] Insuffisamment défini [ ] Non défini [ ]
Problème à résoudre : | Cohérent techniquement [ ] Pertinent / À un niveau BTS SN [ ]
Complexité technique : (liée au support ou au moyen utilisés) | Suffisante [ ] Insuffisante [ ] Exagérée [ ]
Cohérence pédagogique : (relative aux objectifs de l’épreuve) | Le projet permet l’évaluation de toutes les compétences terminales [ ] Chaque candidat peut être évalué sur chacune des compétences [ ]
Planification des tâches demandées aux étudiants, délais prévus, … : | Projet … Défini et raisonnable [ ] Insuffisamment défini [ ] Non défini [ ]
Les revues de projet sont-elles prévues : (dates, modalités, évaluation) | Oui [ ] Non [ ]
Conformité par rapport au référentiel et à la définition de l’épreuve : | Oui [ ] Non [ ]

Observations :

## 8.1 – Avis formulé par la commission de validation :

[ ] Sujet accepté en l’état | [ ] Sujet à revoir : | [ ] Conformité au Référentiel de Certification / Complexité [ ] Définition et planification des tâches [ ] Critères d’évaluation [ ] Autres :
[ ] Sujet rejeté

Motif de la commission :

## 8.2 – Nom des membres de la commission de validation académique :

Nom | Établissement | Académie | Signature

8.3 – Visa de l’autorité académique : | Nota :
(nom, qualité, Académie, signature) | Ce document est contractuel pour la sous-épreuve E6-2 (Projet Technique) et sera joint au « Dossier Technique » de l’étudiant. En cas de modification du cahier des charges, un avenant sera élaboré et joint au dossier du candidat pour présentation au jury, en même temps que le carnet de suivi.

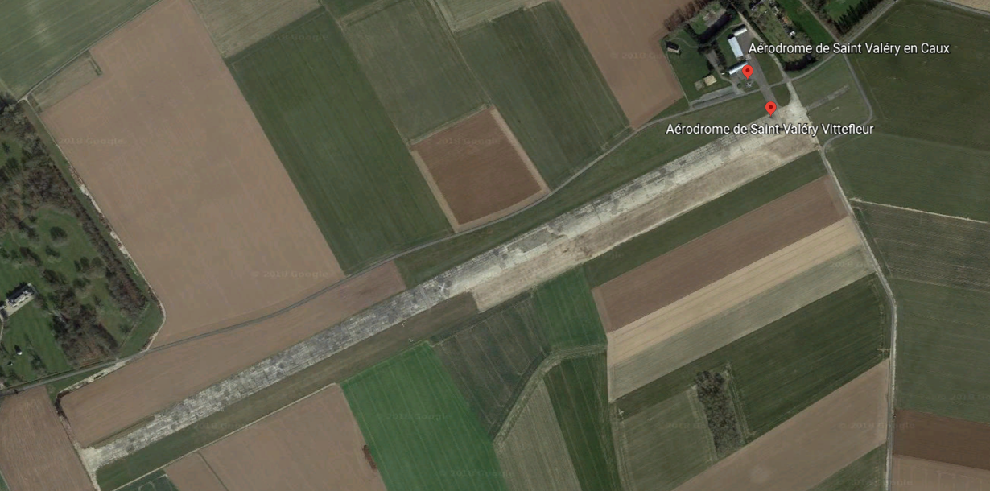
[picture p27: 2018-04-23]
Partie_Alexandre/Image/VueAerienne.PNG

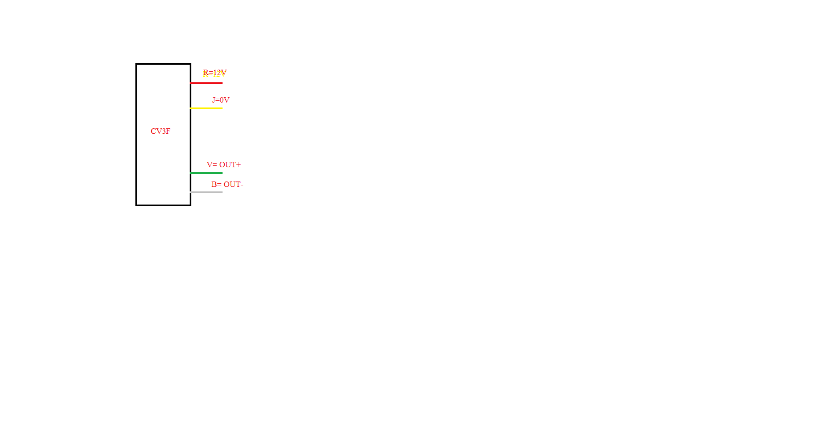
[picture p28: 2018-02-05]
Partie_Remi/Images/IMAGE PROJET/CV3F.png

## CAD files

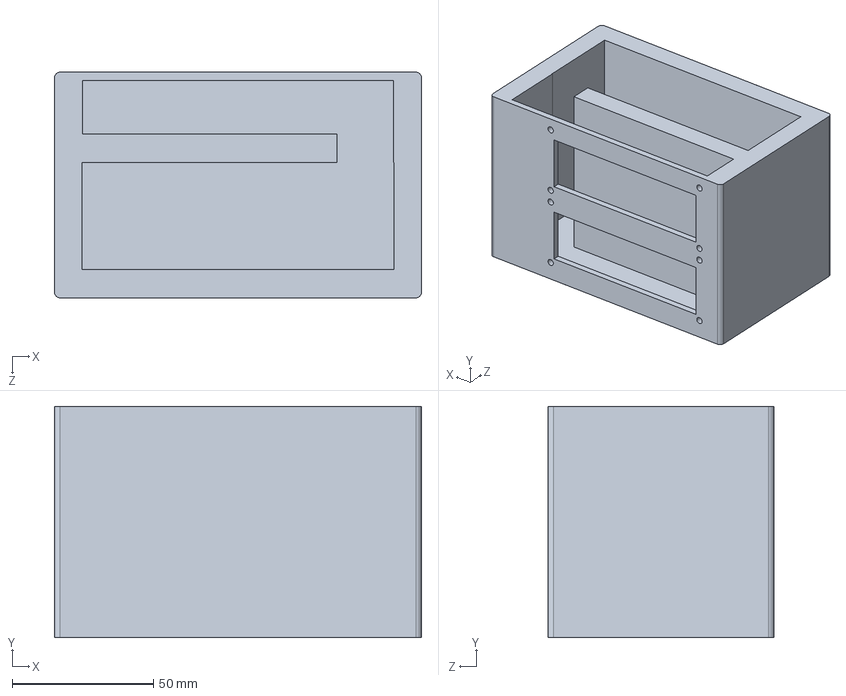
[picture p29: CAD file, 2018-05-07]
Partie_Remi/Pieces SolidWorks/Boitier Afficheur.SLDPRT
130.0 x 82.0 x 80.0 mm

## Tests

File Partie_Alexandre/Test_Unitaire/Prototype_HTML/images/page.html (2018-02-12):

Station météo Aéroclub Saint-Valéry | Logo de l'aéroclub (http://aeroclub.cauchois.free.fr/index.html)

Voici les données météorologiques de la station météo

Relevés météorologiques | | 
Température | ...,..°C
Température | ...,..°F
Vitesse du vent | ...,..kts
Vitesse du vent | ...,..km/h
Humidité | ...%
Pression | ....,..hPa
Direction Vent | ...°

Bonjour. Vous souhaitez visiter le site Internet de l' Aéroclub Cauchois (http://aeroclub.cauchois.free.fr/index.html) ?

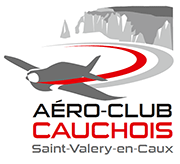
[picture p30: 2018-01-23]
Partie_Alexandre/Test_Unitaire/Test_Remi/img/ACC_sticker.png

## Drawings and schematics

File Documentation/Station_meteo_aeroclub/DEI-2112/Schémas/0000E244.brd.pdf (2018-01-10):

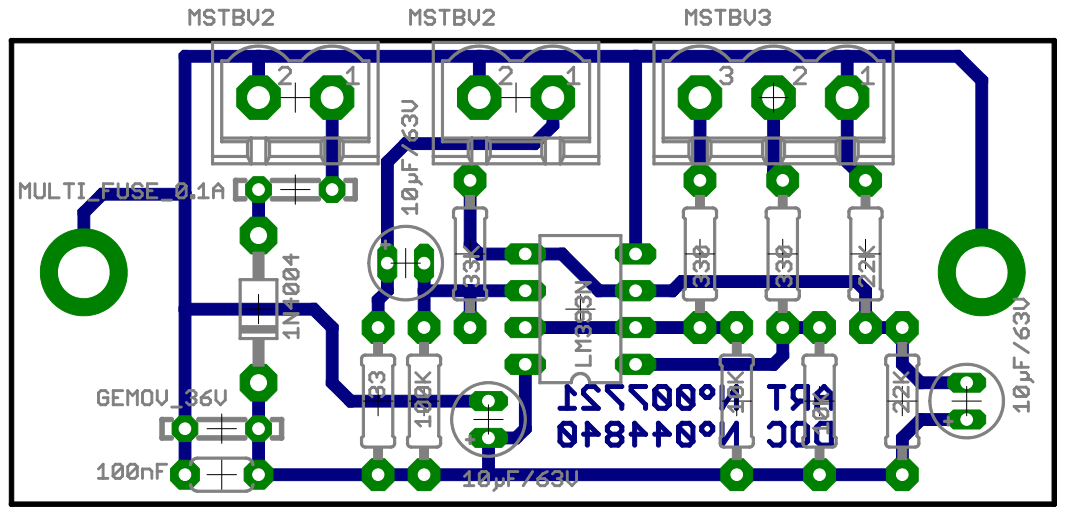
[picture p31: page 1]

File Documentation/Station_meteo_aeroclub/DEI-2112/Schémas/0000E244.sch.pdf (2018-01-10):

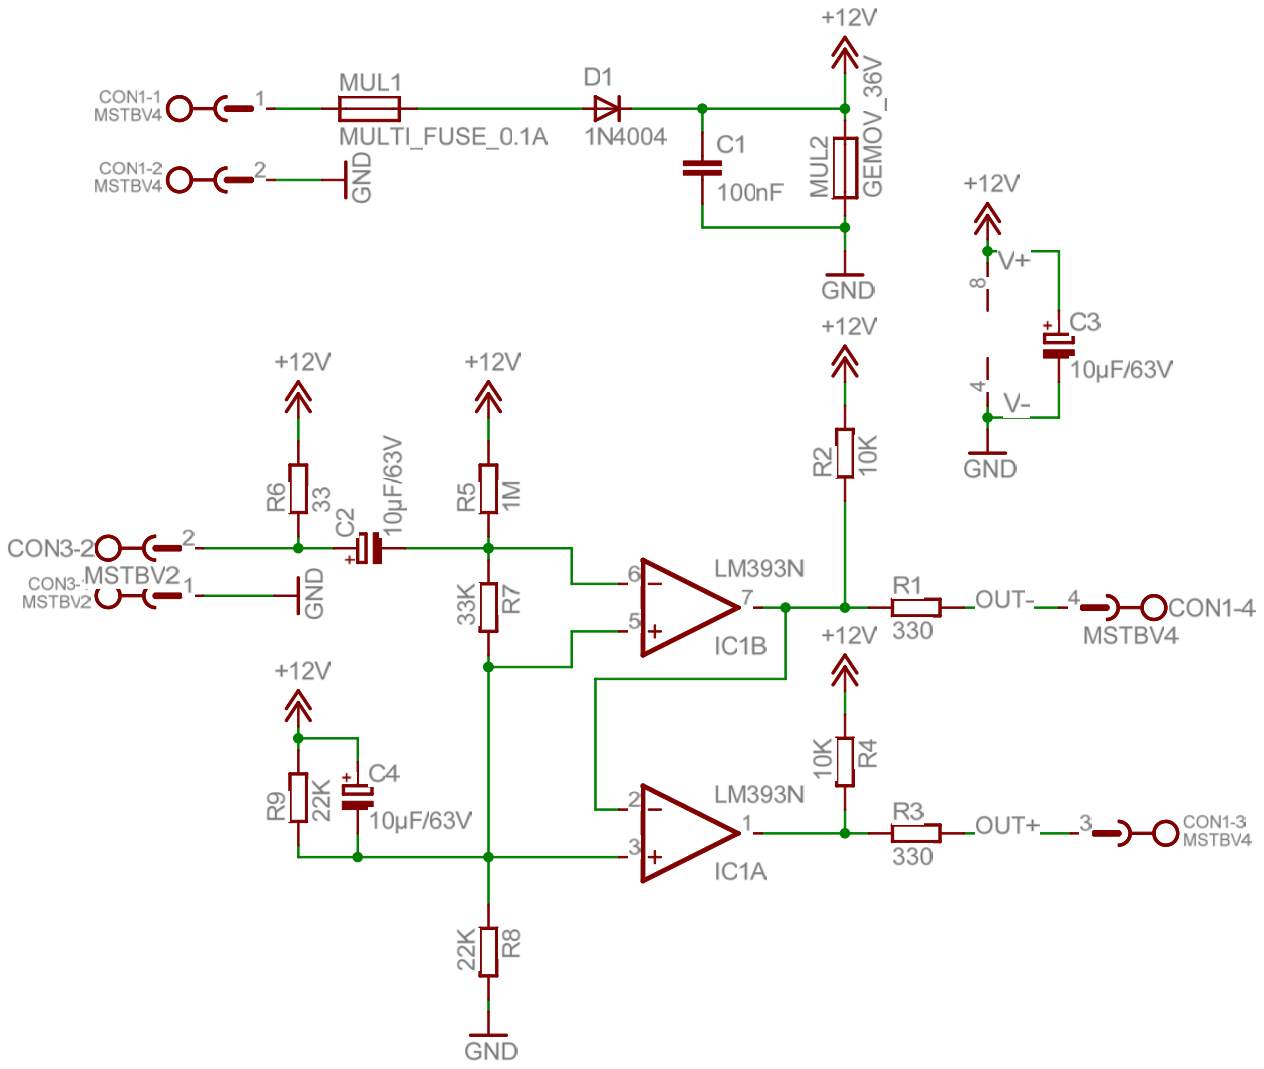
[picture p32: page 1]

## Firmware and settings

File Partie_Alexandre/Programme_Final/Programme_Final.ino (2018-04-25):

/********  Librairie pour la gestion du site Web *******/ 
                       
  #include <Ethernet.h>                
  #include <SPI.h>   
  #include <SD.h>

/********  Librairie pour la gestion des afficheurs *******/                    

  #include <Wire.h>
  #include "CLCD.h"
  #include "I2C.h"
  #include "newChar.h"

/********  Librairie pour la gestion de la trame *******/ 
  
  #include "Inimeac.h"

// [][][][][][][][][][][][][][][][][][][][][][][][][][][][][][]
// []
// []        PROGRAMME PRINCIPAL CREE PAR ALEXANDRE LEBRUN
// []
// []  
// []                PROJET STATION METEO (2018-06)
// []
// [][][][][][][][][][][][][][][][][][][][][][][][][][][][][][]

/********  Creation des variables afficheurs *******/   

  CLCD lcd(0x02,16,2); /* Creation du premiere afficheur avec parametre (adresse du module CLCD, nombre de caractere par ligne, nombre de ligne) */ 
  CLCD lcd1(0x01,16,2); /* Creation du deuxieme afficheur avec parametre (adresse du module CLCD, nombre de caractere par ligne, nombre de ligne) */

/********  Creation de la trame *******/  
  
  Inimeac Trame;  /* Creation de la trame de type Inimeac cette trame hérite de la bibliotheque de Inimeac.h cree par Remi */
  
  char vitesse [5]; /* Creation d'un tableau de caractere pour stocker la donnee vitesse */
  char directionVent [5]; /* Creation d'un tableau de caractere pour stocker la donnee directionVent */
  char temperature [6]; /* Creation d'un tableau de caractere pour stocker la donnee temperature */
  char hygrometrie [7]; /* Creation d'un tableau de caractere pour stocker la donnee hygrometrie */
  char pression [7]; /* Creation d'un tableau de caractere pour stocker la donnee pression */

/********  Creation du serveur web *******/  
  
  byte mac[] = {0x90, 0x98, 0x97, 0x00, 0x05, 0xAB}; /* Creation de l'adresse MAC defini par moi-meme */
  byte ip[] = {192, 168,  190,  123}; /* Creation de l'adresse IP static défini par moi-meme */
  EthernetServer serveur(80); /* Creation d'un server qui ecoute sur le port 80 ( HTTP ) */ 

/********  Creation de la chaine contenant cette trame *******/  
  
  String trameINIMEAC = ""; /* Creation d'une chaine pour contenir les données entrantes */
  boolean trameComplete = false; /* Si la chaîne est complete */

/********  Fonction setup pour les initialisations *******/  
  
  void setup() {
    initI2C(0); /* Initialisation de la vitesse du bus I2C à 0 */
    lcd.init(); /* Initialisation du premiere afficheur I2C */
    lcd1.init(); /* Initialisation du deuxieme afficheur I2C */
    Serial3.begin(9600); /* Initialisation du port série 3 a 9600 bauds */
    Serial.begin(9600); /* Initialisation du port série a 9600 bauds */
    //if (Ethernet.begin(mac) == 0){ /* Condition qui verifie si le serveur DHCP n'est pas present */
        Ethernet.begin(mac, ip); /* Si ce n'est pas le cas le serveur passe en IP¨ defini ci-dessus */
   // }
    Serial.println("adresse ip serveur :");
    Serial.println(Ethernet.localIP()); //on affiche l'adresse IP de la connexion
    serveur.begin();
    trameINIMEAC.reserve(104); /* Reservation de 200 caractere maximum pour la trame */
  }

/********  Fonction loop pour le programme principal *******/  
  
  void loop() {

    siteWeb(); /* Fonction qui integre le siteWeb dans le programme */ 
    
    if (trameComplete) { /* Si la trame est complete */
        Serial.println(trameINIMEAC); /* On affiche cette trame sur le moniteur serie de l'arduino */
        Trame.decodeTrameINIMEAC(trameINIMEAC,true,vitesse,directionVent,temperature,hygrometrie,pression); /* Permet de decoder la trame avec les les differents parametres */
        trameINIMEAC = ""; /* Remet la chaine à zero */
        trameComplete = false; /* Donc trame complete est fausse */
        afficheur(); /* Fonction qui integre les afficheurs dans le programme */
    }   
  }

/********  Fonction serialEvent3 permettant de recuperer la trame *******/
  
  void serialEvent3() {
    while (Serial3.available()) { /* Tant que le port serie 3 est disponible */
      char caractere = (char)Serial3.read(); /* On prend les nouveaux octets */
      trameINIMEAC += caractere; /* On ajoute les nouveaux octets dans la variable trameINIMEAC */
      if (caractere == '\n') {  /* Si le prochain caractere est un caractere de nouvelle ligne */
        trameComplete = true;  /* on met la trameComplete a vrai */
      }
    }
    Serial3.flush(); /* On vide le buffer du port serie 3 */
  }

/********  Fonction siteWeb regroupant la pageWeb et le serveur *******/  

  void siteWeb() {
    
    EthernetClient client = serveur.available(); /* on écoute le port */
    if (client) { /* si client connecté */
      if (client.connected()) { /* si le client est en connecté */
        pageWeb(client); /* fonction pour l'entête de la page HTML */
        client.stop(); /* on déconnecte le client */
      }
    }
  }

/********  Fonction pageWeb qui regroupe l'HTML et le CSS *******/   
  
  void pageWeb(EthernetClient cl) {
    
    //infos pour le navigateur
    
    cl.println("HTTP/1.1 200 OK"); // type du HTML
    cl.println("Content-Type: text/html; charset=UTF-8 "); //type de fichier et encodage des caractères
    cl.println("Connection: close");  // fermeture de la connexion quand toute la réponse sera envoyée
    cl.println("Refresh: 5");  // rafraîchissement automatique de la page toutes les 5 secondes
    cl.println();
    
    //balises d'entête
    
    cl.println("<!DOCTYPE HTML>");
    cl.println("<html>");
      cl.println("<head>");
        cl.println("<title>Station météo</title>");
        cl.println("<link rel=\"icon\" type=\"image/ico\" href=\"http://www.icone-png.com/ico/26/25788.ico\"/>");
      
        //CSS
        
        cl.println("<style type=text/css>");
        cl.println("body{margin-left:auto;");
        cl.println("margin-right:auto;");
        cl.println("cursor: url(https://icon-icons.com/icons2/308/PNG/32/plane-icon_34103.png), default;");
        cl.println("font-family:\"Century Gothic\",serif;");
        cl.println("text-align:center;");
        cl.println("background-color : #ca0000;");
        cl.println("max-width:800px;}");
        cl.println("#entete{text-align:center;");
        cl.println("margin-left:auto;");
        cl.println("margin-right:auto;");
        cl.println("min-width:600px;");
        cl.println("padding-bottom:20px;}");
        cl.println("#donnee {padding-top:40px;");
        cl.println("margin-left:auto;"); 
        cl.println("padding-bottom:343px;");
        cl.println("font-size:24px;");
        cl.println("margin-right:auto;}");
        cl.println(".donne1 {border:thin solid black;");
        cl.println("vertical-align:middle;");
        cl.println("text-align:center;");
        cl.println("min-width:200px;}");
        cl.println("#Introduction,#piedpage {border:thin black solid;}");
        cl.println("#CentrePage{background-color : white;}");
        cl.println("a:hover{cursor: url(https://icon-icons.com/icons2/907/PNG/32/commercial-aeroplane-bottom-view_icon-icons.com_70518.png), pointer;");
        cl.println("color: #ca0000;}");
        cl.println("</style>");
  
      cl.println("</head>");
   
    //Corps page
    
      cl.println("<body>");
        cl.println("<div id=\"CentrePage\">");
        
            //Baniere
            
        cl.println("<table id=\"entete\">");
          cl.println("<tr>");
            cl.println("<td><h1>STATION MÉTÉO <br/>AÉRO-CLUB SAINT-VALÉRY</h1></td>");
            cl.println("<td><p><a href=\"http://aeroclub.cauchois.free.fr/index.html\" target=\"_blank\"><img src=\"http://aeroclub.cauchois.free.fr/images/ACC_sticker.png\" alt=\"Logo de l'aéroclub\" /></a></p></td>");
          cl.println("</tr>");
        cl.println("</table>");
        
            //Tableau de donnée
        
        cl.println("<div id=\"Introduction\">");
          cl.println("<p>Voici les données météorologiques de la station météo </p>");
        cl.println("</div>");
        
        cl.println("<div id=\"corps\">");
          cl.println("<table id=\"donnee\">");
            cl.println("<tr>");
              cl.println("<td class=\"donne1\" colspan=\"2\"><h2> Relevés météorologiques <br /></h2></td>");
              cl.println("<td class=\"donne1\" rowspan=\"8\"><img src=\"http://www.qu-est-ce.com/wp-content/uploads/2013/01/dessin-de-rose-des-vents.jpg\" alt=\"logo\"/></td>");
            cl.println("</tr>");
            cl.println("<tr>");
              cl.println("<td class=\"donne1\" rowspan=\"2\"> Vitesse du vent </td>");
              cl.println("<td class=\"donne1\">");
              if ((vitesse [0]=='0' || vitesse [0]==' ') && ( vitesse [1]=='0' || vitesse [1]==' ')){
                vitesse [0]=' ';
                vitesse [1]=' ';
                cl.print(vitesse [0]);
                cl.print(vitesse [1]);
                cl.print(vitesse [2]);
                cl.print(vitesse [3]);
                cl.print(vitesse [4]);
                cl.print(vitesse [5]);
              }else if (vitesse [0]=='0' || vitesse [0]==' '){
                vitesse [0]=' ';
                cl.print(vitesse [0]);
                cl.print(vitesse [1]);
                cl.print(vitesse [2]);
                cl.print(vitesse [3]);
                cl.print(vitesse [4]);
                cl.print(vitesse [5]);
              }
              cl.println(" kts </td>");
            cl.println("</tr>");
            cl.println("<tr>");
                cl.println("<td class=\"donne1\">");
                      if (vitesse [1]==' '){
                          cl.print((((float(vitesse [2])-48)) +  ((float(vitesse [4])-48)/10) +  ((float(vitesse [5])-48)/100) )*1.852);
                      }
                      else{
                      cl.print((((float(vitesse [1]-48)*10)) + ((float(vitesse [2])-48)) +  ((float(vitesse [4])-48)/10) +  ((float(vitesse [5])-48)/100) )*1.852); 
                      }
                cl.println(" km/h </td>");
            cl.println("</tr>");
            cl.println("<tr>");
              cl.println("<td class=\"donne1\"> Direction du Vent </td>");
              cl.println("<td class=\"donne1\">");
              if (directionVent [0]=='0' || directionVent [0]==' '){
                directionVent [0]= ' ';
                cl.print(directionVent [0]);
                cl.print(directionVent [1]);
                cl.print(directionVent [2]);
              }else{
                cl.print(directionVent [0]);
                cl.print(directionVent [1]);
                cl.print(directionVent [2]);
              }
              cl.println(" ° </td>");
            cl.println("</tr>");
            cl.println("<tr>");
              cl.println("<td class=\"donne1\" rowspan=\"2\"> Température </td>");
              cl.println("<td class=\"donne1\">");
                cl.print(temperature [0]);
                cl.print(temperature [1]);
                cl.print(temperature [2]);
                cl.print(temperature [3]);
                cl.print(temperature [4]);
              cl.println(" °C</td>");
            cl.println("</tr>");
            cl.println("<tr>");
                cl.println("<td class=\"donne1\">");
                      cl.print(((((float(temperature [0])-48)*10) + (float(temperature [1])-48) + ((float(temperature [3])-48)/10) + ((float(temperature [4])-48)/100))*9)/5+32); 
                cl.println(" °F </td>");
            cl.println("</tr>");
            cl.println("<tr>");
              cl.println("<td class=\"donne1\"> Pression </td>");
              cl.println("<td class=\"donne1\">");
              if (pression [0]!='1'){
                if (pression [0]==':'){
                  if (pression [1]=='1'){
                    cl.print(pression [1]);
                    cl.print(pression [2]);
                    cl.print(pression [3]);
                    cl.print(pression [4]);
                    cl.print(pression [5]);
                    cl.print(pression [6]);
                    cl.print(pression [7]);
                  }else{
                    cl.print(pression [1]);
                    cl.print(pression [2]);
                    cl.print(pression [3]);
                    cl.print(pression [4]);
                    cl.print(pression [5]);
                    cl.print(pression [6]);
                }
                }else{
                cl.print(pression [0]);
                cl.print(pression [1]);
                cl.print(pression [2]);
                cl.print(pression [3]);
                cl.print(pression [4]);
                cl.print(pression [5]);
                }
              }else{
                cl.print(pression [0]);
                cl.print(pression [1]);
                cl.print(pression [2]);
                cl.print(pression [3]);
                cl.print(pression [4]);
                cl.print(pression [5]);
                cl.print(pression [6]);
              }
              cl.println(" hPa </td>");
            cl.println("</tr>");
            cl.println("<tr>");
              cl.println("<td class=\"donne1\"> Humidité </td>");
              cl.println("<td class=\"donne1\">");
              if (hygrometrie [1]!='1'){
                cl.print(hygrometrie [1]);
                cl.print(hygrometrie [2]);
                cl.print(hygrometrie [3]);
                cl.print(hygrometrie [4]);
                cl.print(hygrometrie [5]);
              }else{
                cl.print(hygrometrie [1]);
                cl.print(hygrometrie [2]);
                cl.print(hygrometrie [3]);
                cl.print(hygrometrie [4]);
                cl.print(hygrometrie [5]);
                cl.print(hygrometrie [6]);
              }
              cl.println(" % </td>");
            cl.println("</tr>");
          cl.println("</table>");
        cl.println("</div>");
        cl.println("<div id=\"piedpage\">");
          cl.println("<p> Bonjour. Vous souhaitez visiter le site internet de l' <a  href=\"http://aeroclub.cauchois.free.fr/index.html\" target=\"_blank\">Aéroclub Cauchois </a> ?<br /></p>");
        cl.println("</div>");
        
        cl.println("</div>");
      cl.println("</body>");
    cl.println("</html>");
  }

/********  Fonction afficheur pour l'affichage des deux ecrans I2C *******/ 
  
  void afficheur(void){
                              
    lcd.setCursor(0,0);
    lcd.print(temperature [0]);
    lcd.print(temperature [1]);
    lcd.print(temperature [2]);
    lcd.print(temperature [3]);
    lcd.print(char(223));
    lcd.print("C");


    if (pression [0]!='1'){
      if (pression [0]==':'){
        if (pression [1]=='1'){
          lcd.setCursor(1,0);
    lcd.print(pression [1]);
    lcd.print(pression [2]);
    lcd.print(pression [3]);
    lcd.print(pression [4]);
    lcd.print(pression [5]);
    lcd.print(pression [6]);
    lcd.print("hPa");
    
        }else{
    lcd.setCursor(1,0);
    lcd.print(pression [1]);
    lcd.print(pression [2]);
    lcd.print(pression [3]);
    lcd.print(pression [4]);
    lcd.print(pression [5]);
    lcd.print("hPa");
        }
    }else{
        lcd.setCursor(1,0);
        lcd.print(pression [0]);
        lcd.print(pression [1]);
        lcd.print(pression [2]);
        lcd.print(pression [3]);
        lcd.print(pression [4]);
        lcd.print("hPa");
      }
    }else{
       lcd.setCursor(1,0);
        lcd.print(pression [0]);
        lcd.print(pression [1]);
        lcd.print(pression [2]);
        lcd.print(pression [3]);
        lcd.print(pression [4]);
        lcd.print(pression [5]);
        lcd.print("hPa");
       }
    
    
    if (hygrometrie [1]!='1'){
    lcd.setCursor(0,11);
    lcd.print(hygrometrie [1]);
    lcd.print(hygrometrie [2]);
    lcd.print(hygrometrie [3]);
    lcd.print(hygrometrie [4]);
    lcd.print("%");
    lcd.cursor_off();
    }else{
      lcd.setCursor(0,10);
      lcd.print(hygrometrie [1]);
      lcd.print(hygrometrie [2]);
      lcd.print(hygrometrie [3]);
      lcd.print(hygrometrie [4]);
      lcd.print(hygrometrie [5]);
      lcd.print("%");
      lcd.cursor_off();
    }

    if ((vitesse [0]=='0' || vitesse [0]==' ') && ( vitesse [1]=='0' || vitesse [1]==' ')){
      vitesse [0]=' ';
      vitesse [1]=' ';
      lcd1.setCursor(0,0);
      lcd1.print(vitesse [2]);
      lcd1.print(vitesse [3]);
      lcd1.print(vitesse [4]);
      lcd1.print("kts");
      }else if (vitesse [0]=='0' || vitesse [0]==' '){
        vitesse [0]=' ';
        lcd1.setCursor(0,0);
        lcd1.print(vitesse [1]);
        lcd1.print(vitesse [2]);
        lcd1.print(vitesse [3]);
        lcd1.print(vitesse [4]);
        lcd1.print(vitesse [5]);
        lcd1.print("kts");
      }
    
      if (directionVent [0]=='0' || directionVent [0]==' '){
        directionVent [0]= ' ';
        lcd1.setCursor(1,0);
        lcd1.print(directionVent [1]);
        lcd1.print(directionVent [2]);
        lcd1.print(char(223));
        lcd1.print(" ");
        lcd1.cursor_off();
        }else{
          lcd1.setCursor(1,0);
          lcd1.print(directionVent [0]);
          lcd1.print(directionVent [1]);
          lcd1.print(directionVent [2]);
          lcd1.print(char(223));
          lcd1.cursor_off();
        }
}

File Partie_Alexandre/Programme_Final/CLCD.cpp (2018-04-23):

#include <LiquidCrystal.h>

// [][][][][][][][][][][][][][][][][][][][][][][][][][][][][][]
// []
// []	LCD API for Lextronic CCLCD I2C models
// []
// []  
// []   Library by julien@pobot.org (2011-10)
// []
// [][][][][][][][][][][][][][][][][][][][][][][][][][][][][][]

#include <Wire.h>

#include <string.h>			//needed for strlen()

#include <inttypes.h>

#include "Arduino.h"		//all things wiring / arduino

#include "CLCD.h"

#define _LCDEXPANDED				// If defined turn on advanced functions

// Global Vars 

uint8_t g_num_lines = 4;
uint8_t g_num_col = 20;

int g_cmdDelay = 50;
int g_charDelay = 0;

// [][][][][][][][][][][][][][][][][][][][][][][][][][][][][][]
// []
// []	Class Constructor 
// []
// []	num_lines = 1-4
// []   num_col = 1-80
// []  
// []   
// []
// [][][][][][][][][][][][][][][][][][][][][][][][][][][][][][]

CLCD::CLCD (uint8_t address,uint8_t num_col,uint8_t num_lines)
{

  _Addr = address;
  g_num_lines = num_lines;
  g_num_col = num_col;

}

// [][][][][][][][][][][][][][][][][][][][][][][][][][][][][][]
// []
// []	initiatize lcd after a short pause
// []
// []	
// []   Put the display in some kind of known mode
// []   Put the cursor at 0,0
// []
// [][][][][][][][][][][][][][][][][][][][][][][][][][][][][][]


void CLCD::init () {

  Wire.begin();
  off();
  clear();
  blink_off();
  cursor_off(); 
  home();

}

// [][][][][][][][][][][][][][][][][][][][][][][][][][][][][][]
// []
// []	Over ride the default delays used to write commands to the display
// []
// []	The default values are set by the library
// []   this allows the programer to take into account code delays
// []   and speed things up.
// []   
// []
// [][][][][][][][][][][][][][][][][][][][][][][][][][][][][][]


void CLCD::setDelay (int cmdDelay,int charDelay) {

  g_cmdDelay = cmdDelay;
  g_charDelay = charDelay;

}




// [][][][][][][][][][][][][][][][][][][][][][][][][][][][][][]
// []
// []   write a command to the display. 
// []
// [][][][][][][][][][][][][][][][][][][][][][][][][][][][][][]


void CLCD::command(uint8_t value) {

  delay(g_cmdDelay);
}


// [][][][][][][][][][][][][][][][][][][][][][][][][][][][][][]
// []
// []   write a command to the display. 
// []
// []	This is also used by the print, and println
// []	
// []
// [][][][][][][][][][][][][][][][][][][][][][][][][][][][][][]



size_t CLCD::write(uint8_t value) {

  Wire.beginTransmission(_Addr);
  Wire.write(value);
  Wire.endTransmission();
  delay(g_charDelay);

  return sizeof value;
}



// [][][][][][][][][][][][][][][][][][][][][][][][][][][][][][]
// []
// []	Clear the display, and put cursor at 0,0 
// []
// []
// [][][][][][][][][][][][][][][][][][][][][][][][][][][][][][]


void CLCD::clear(){

  Wire.beginTransmission(_Addr);
  Wire.write(0x1B);
  Wire.write(0x43);
  delay(g_cmdDelay);
  Wire.endTransmission();

}

// [][][][][][][][][][][][][][][][][][][][][][][][][][][][][][]
// []
// []	Home to custor to 0,0
// []
// []	Do not disturb data on the displayClear the display
// []
// []
// [][][][][][][][][][][][][][][][][][][][][][][][][][][][][][]


void CLCD::home(){

  setCursor(0,0);					// The command to home the cursor does not work on the version 1.3 of the display
}


// [][][][][][][][][][][][][][][][][][][][][][][][][][][][][][]
// []
// []	Turn on the display
// []
// []	Depending on the display, might just turn backlighting on
// []
// []
// [][][][][][][][][][][][][][][][][][][][][][][][][][][][][][]

void CLCD::backlight(){
  on(); 
}

void CLCD::on(){

  Wire.beginTransmission(_Addr);
  Wire.write(0x1B);
  Wire.write(0x42);
  Wire.endTransmission();
  delay(g_cmdDelay);
}


// [][][][][][][][][][][][][][][][][][][][][][][][][][][][][][]
// []
// []	Turn off the display
// []
// []	Depending on the display, might just turn backlighting off
// []
// []
// [][][][][][][][][][][][][][][][][][][][][][][][][][][][][][]

void CLCD::off(){

  Wire.beginTransmission(_Addr);
  Wire.write(0x1B);
  Wire.write(0x62);
  Wire.endTransmission();
  delay(g_cmdDelay);

}


// [][][][][][][][][][][][][][][][][][][][][][][][][][][][][][]
// []
// []	Turn on the underline cursor
// []
// []
// [][][][][][][][][][][][][][][][][][][][][][][][][][][][][][]

void CLCD::cursor_on(){

  Wire.beginTransmission(_Addr);
  Wire.write(0x1B);
  Wire.write(0x53);
  Wire.endTransmission();
  delay(g_cmdDelay);

}


// [][][][][][][][][][][][][][][][][][][][][][][][][][][][][][]
// []
// []	Turn off the underline cursor
// []
// []
// [][][][][][][][][][][][][][][][][][][][][][][][][][][][][][]

void CLCD::cursor_off(){

  Wire.beginTransmission(_Addr);
  Wire.write(0x1B);
  Wire.write(0x73);
  Wire.endTransmission();

}


// [][][][][][][][][][][][][][][][][][][][][][][][][][][][][][]
// []
// []	Turn on the blinking block cursor
// []
// []
// [][][][][][][][][][][][][][][][][][][][][][][][][][][][][][]


void CLCD::blink_on(){


}


// [][][][][][][][][][][][][][][][][][][][][][][][][][][][][][]
// []
// []	Turn off the blinking block cursor
// []
// []
// [][][][][][][][][][][][][][][][][][][][][][][][][][][][][][]

void CLCD::blink_off(){

}


// [][][][][][][][][][][][][][][][][][][][][][][][][][][][][][]
// []
// []	Position the cursor to position line,column
// []
// []	line is 0 - Max Display lines
// []	column 0 - Max Display Width
// []
// [][][][][][][][][][][][][][][][][][][][][][][][][][][][][][]


void CLCD::setCursor(uint8_t line_num, uint8_t x){

  Wire.beginTransmission(_Addr);
  Wire.write(0x1B);
  Wire.write(0x4C);
  Wire.write(min(x,g_num_col));
  Wire.write(min(line_num,g_num_lines));
  Wire.endTransmission();
  delay(g_cmdDelay);

}


// [][][][][][][][][][][][][][][][][][][][][][][][][][][][][][]
// []
// []	Return the status of the display
// []
// []	Does nothing on this display
// []
// [][][][][][][][][][][][][][][][][][][][][][][][][][][][][][]	

uint8_t CLCD::status(){

  return 0;
}


// [][][][][][][][][][][][][][][][][][][][][][][][][][][][][][]
// []
// []	Read data from keypad
// []
// []	
// []	
// []
// [][][][][][][][][][][][][][][][][][][][][][][][][][][][][][]


uint8_t CLCD::keypad (){


}



// [][][][][][][][][][][][][][][][][][][][][][][][][][][][][][]
// []
// []	Load data for a custom character
// []
// []	Char = custom character number 0-7
// []	Row is array of chars containing bytes 0-7
// []
// []
// [][][][][][][][][][][][][][][][][][][][][][][][][][][][][][]


void CLCD::load_custom_character(uint8_t char_num, uint8_t *rows)
{


}



void CLCD::setBacklight(uint8_t new_val)
{
  if (new_val) {
    on(); 
  } 
  else {
    off();
  }
}


void CLCD::setContrast(uint8_t new_val)
{

}

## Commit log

2017-12-19 Creation Partie Projet
    Ajout de Partie pour chaque Etudiant
2017-12-19 Creation Projet
    Ajout de Dossiers
2018-01-08 Ajout des différents diagrammes SysML
2018-01-09 Ajout des scénarios principaux pour le diagramme de cas d'utilisation :þ
2018-01-10 Ajout diagramme de séquence Application, Site Web et modification diagramme de séquence principal
2018-01-10 Ajout de la documentation Technique
2018-01-11 Image des differents diagrammes ajouter
2018-01-22 Modification des diagrammes SysML
2018-01-23 Ajout du logo de l'aéroclub de saint valéry, modification des diagrammes SysML et modification des scénarios Signed-off-by: LebrunAlexandre <Lebrun.Alexandre.Pro@gmail.com>
2018-01-23 Ajout de photo du capteur HIH8120 determiné avec son datasheet Ajout d'image pour la pression et l'altitude
2018-01-25 - Ajout dans ma partie du protocole de communication INIMEAC cree pour communiquer les differentes informations - Ajout de classe CapteurCV3F et HIH8120
2018-01-29 Ajout de la bibliotheque du capteur BMP180 Signed-off-by: Delaune-Remi <remidelaune.pro@gmail.com>
2018-02-02 Creation du bibliotheque permettant d'encoder la trame INIMEAC
2018-02-05 - Creation d'un compte rendu sur les differents capteurs utilises - Ajout schema pour l'adaptation de tension du CV3F - Ajout schema de cablage du capteur CV3F
2018-02-07 Creation d'un programme de lecture de la trameNMEA
2018-02-12 Ajout de programmes de test Signed-off-by: Delaune-Remi <remidelaune.pro@gmail.com>
2018-02-13 -Ajout d'un programme permettant la lecture des donnees du capteur HIH8120
2018-02-14 - Ajout de programme test creation des trames INIMEAC - Ajout de programme test reception BMP180 - Ajout de programme test reception HIH8120 - Ajout de programme test conversion double to string - Mi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
2018-02-19 Modification du programme de test pour la creation de la trame INIMEAC Signed-off-by: Delaune-Remi <remidelaune.pro@gmail.com>
2018-04-23 Alexandre
    Ajout d'un début de sommaire
2018-04-24 Diagramme de Séquence
    Changement du diagramme
2018-04-24 Diagramme de Blocs
    Insertion Diagramme de Blocs
2018-04-29 Ajout
    Création d'un boitier pour les afficheurs
    [Boitier Afficheur.SLDPRT]
2018-05-07 Partie remi
    amelioration
    [Boitier Afficheur.SLDPRT]
